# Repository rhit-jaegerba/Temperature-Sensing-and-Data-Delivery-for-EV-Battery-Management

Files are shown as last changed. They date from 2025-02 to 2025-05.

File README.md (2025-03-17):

# Temperature Sensing and Data Delivery for EV Battery Management

This repository contains the codebase for **Temperature Sensing and Data Delivery for EV Battery Management**, a project focused on collecting, processing, and transmitting temperature data to enhance electric vehicle (EV) battery management systems.

## Authors
- Beckett Jaeger  
- Ryan Seidel  
- Alex Herzog  
- Dylan McCain  

## Advisors
- Dr. JianJian Song  
- Dr. Mario Simoni  

## Clients
- Greg Romas  
- Marc Herniter  
- **BWC Team**:  
  - Jack Martin  
  - Jasper Halford  

## Project Details
This project is being developed as part of **Team 09** for the **Senior Design Program** at Rose-Hulman Institute of Technology (2024-2025 academic year).  

It is designed specifically for the **Rose-Hulman Battery Workforce** in support of the **Vigo Voltage Competition Team**, aiming to deliver a reliable, efficient, and scalable system for monitoring and transmitting temperature data critical to the performance and safety of EV battery systems.

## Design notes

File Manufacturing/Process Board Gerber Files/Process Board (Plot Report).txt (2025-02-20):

Plot Report
-----------

Report Written:     Wednesday, February 19, 2025
Project Path:       C:\Users\mccaindm\OneDrive - Rose-Hulman Institute of Technology\Senior Des\Process Board PCB\Process Board\Process Board.prj
Design Path:        C:\Users\mccaindm\OneDrive - Rose-Hulman Institute of Technology\Senior Des\Process Board PCB\Process Board\Process Board.pcb
Design Title:       
Created:            1/19/2025 3:18:48 PM
Last Saved:         2/18/2025 1:24:20 PM
Editing Time:       731 min
Units:              mil (precision 2)

Device Settings
===============

Gerber Settings
===============

    Leading zero suppression.
    G01 assumed throughout.
    Line termination <*> <CR> <LF>.
    3.5 format absolute inches.

    Format commands defined in Gerber file.
    Aperture table defined in Gerber file.
    Hardware arcs allowed.

Drill Settings
==============

    Excellon Format 2
    Format 3.5 absolute in mm.
    Zero suppression Leading

Plots Output
============

    Plot Job: "C:\Users\mccaindm\OneDrive - Rose-Hulman Institute of Technology\Senior Des\Process Board PCB\Process Board\Process Board.mop"

Gerber Output
=============

C:\Users\mccaindm\OneDrive - Rose-Hulman Institute of Technology\Senior Des\Process Board PCB\Process Board\Process Board - Top Silkscreen.gbr

    Layers:
    ------------------
    Top Silkscreen

    D-Code Shape  (thou)
    -----------------------
    D16    Round 11.81
    D20    Round 1.97
    D21    Round 3.94
    D73    Round 5.00
    D74    Round 7.87
    D75    Round 9.84
    D124   Round 3.00

Gerber Output
=============

C:\Users\mccaindm\OneDrive - Rose-Hulman Institute of Technology\Senior Des\Process Board PCB\Process Board\Process Board - Top Copper.gbr

    Layers:
    --------------
    Top Copper

    D-Code Shape  (thou)
    -----------------------------------------------
    D16    Round 11.81
    D18    Round 8.00
    D19    Round 32.00
    D70    Round 66.00
    D71    Round 141.73
    D77    Rectangle 23.62 X 47.24
    D78    Rectangle 23.62 X 47.24  Rotation 90
    D79    Rectangle 11.81 X 31.50  Rotation 90
    D80    Rectangle 11.81 X 31.50
    D81    Square 110.24
    D82    Rectangle 47.24 X 125.98
    D83    Rectangle 66.93 X 208.66
    D84    Rectangle 23.62 X 24.41  Rotation 90
    D85    Rectangle 39.76 X 71.65
    D86    Rectangle 23.62 X 49.21  Rotation 90
    D87    Rectangle 17.72 X 23.62  Rotation 90
    D88    Rectangle 62.99 X 125.98
    D89    Rectangle 23.62 X 24.41
    D90    Rectangle 23.62 X 49.21
    D91    Rectangle 17.72 X 23.62
    D92    Rectangle 37.40 X 110.24
    D93    Rectangle 95.00 X 135.00  Rotation 90
    D94    Rectangle 18.70 X 19.69  Rotation 90
    D95    Rectangle 18.70 X 19.69
    D96    Rectangle 43.31 X 78.74
    D97    Square 31.50
    D125   Rectangle 47.24 X 125.98  Rotation 90
    D126   Rectangle 66.93 X 208.66  Rotation 90

Gerber Output
=============

C:\Users\mccaindm\OneDrive - Rose-Hulman Institute of Technology\Senior Des\Process Board PCB\Process Board\Process Board - Top Solder Mask.gbr

    Layers:
    -------------------
    Top Solder Mask

    D-Code Shape  (thou)
    ------------------------------------------------
    D23    Round 38.00
    D24    Round 72.00
    D25    Round 147.73
    D99    Rectangle 29.62 X 53.24
    D100   Rectangle 29.62 X 53.24  Rotation 90
    D101   Rectangle 17.81 X 37.50  Rotation 90
    D102   Rectangle 17.81 X 37.50
    D103   Square 116.24
    D104   Rectangle 53.24 X 131.98
    D105   Rectangle 72.93 X 214.66
    D106   Rectangle 29.62 X 30.41  Rotation 90
    D107   Rectangle 45.76 X 77.65
    D108   Rectangle 29.62 X 55.21  Rotation 90
    D109   Rectangle 23.72 X 29.62  Rotation 90
    D110   Rectangle 68.99 X 131.98
    D111   Rectangle 29.62 X 30.41
    D112   Rectangle 29.62 X 55.21
    D113   Rectangle 23.72 X 29.62
    D114   Rectangle 43.40 X 116.24
    D115   Rectangle 101.00 X 141.00  Rotation 90
    D116   Rectangle 24.70 X 25.69  Rotation 90
    D117   Rectangle 24.70 X 25.69
    D118   Rectangle 49.31 X 84.74
    D119   Square 37.50
    D127   Rectangle 53.24 X 131.98  Rotation 90
    D128   Rectangle 72.93 X 214.66  Rotation 90

Gerber Output
=============

C:\Users\mccaindm\OneDrive - Rose-Hulman Institute of Technology\Senior Des\Process Board PCB\Process Board\Process Board - Top Paste Mask.gbr

    Layers:
    ------------------
    Top Paste Mask

    D-Code Shape  (thou)
    -----------------------------------------------
    D120   Rectangle 37.31 X 72.74
    D121   Square 25.50
    D129   Rectangle 41.24 X 119.98  Rotation 90
    D130   Rectangle 60.93 X 202.66  Rotation 90
    D150   Rectangle 17.62 X 41.24
    D151   Rectangle 17.62 X 41.24  Rotation 90
    D152   Rectangle 5.81 X 25.50  Rotation 90
    D153   Rectangle 5.81 X 25.50
    D154   Square 104.24
    D155   Rectangle 41.24 X 119.98
    D156   Rectangle 60.93 X 202.66
    D157   Rectangle 17.62 X 18.41  Rotation 90
    D158   Rectangle 33.76 X 65.65
    D159   Rectangle 17.62 X 43.21  Rotation 90
    D160   Rectangle 11.72 X 17.62  Rotation 90
    D161   Rectangle 56.99 X 119.98
    D162   Rectangle 17.62 X 18.41
    D163   Rectangle 17.62 X 43.21
    D164   Rectangle 11.72 X 17.62
    D165   Rectangle 31.40 X 104.24
    D166   Rectangle 89.00 X 129.00  Rotation 90
    D167   Rectangle 12.70 X 13.69  Rotation 90
    D168   Rectangle 12.70 X 13.69

Gerber Output
=============

C:\Users\mccaindm\OneDrive - Rose-Hulman Institute of Technology\Senior Des\Process Board PCB\Process Board\Process Board - GND Plane (Power Plane).gbr

    Layers:
    -----------------------------------------------------------------------------------
    GND Plane  - Plane Isolation Gap 10.00 Thermal Connect Width 10.00 with 4 Spokes

    D-Code Shape  (thou)
    -----------------------------------------
    D12    Round 46.00
    D13    Round 80.00
    D14    Round 66.00  Thermal Relief Pad
    D15    Round 155.73
    D131   Round 32.00  Thermal Relief Pad

Gerber Output
=============

C:\Users\mccaindm\OneDrive - Rose-Hulman Institute of Technology\Senior Des\Process Board PCB\Process Board\Process Board - V3.3 Plane (Power Plane).gbr

    Layers:
    ------------------------------------------------------------------------------------
    V3.3 Plane  - Plane Isolation Gap 10.00 Thermal Connect Width 10.00 with 4 Spokes

    D-Code Shape  (thou)
    -----------------------------------------
    D12    Round 46.00
    D13    Round 80.00
    D15    Round 155.73
    D131   Round 32.00  Thermal Relief Pad

Gerber Output
=============

C:\Users\mccaindm\OneDrive - Rose-Hulman Institute of Technology\Senior Des\Process Board PCB\Process Board\Process Board - Bottom Copper.gbr

    Layers:
    -----------------
    Bottom Copper

    D-Code Shape  (thou)
    -----------------------
    D10    Round 11.81
    D11    Round 32.00
    D12    Round 8.00
    D13    Round 66.00
    D14    Round 141.73

Gerber Output
=============

C:\Users\mccaindm\OneDrive - Rose-Hulman Institute of Technology\Senior Des\Process Board PCB\Process Board\Process Board - Bottom Documentation.gbr

    Layers:
    ------------------------
    Bottom Documentation

    D-Code Shape  (thou)
    -----------------------
    D15    Round 1.97
    D16    Round 3.94

Gerber Output
=============

C:\Users\mccaindm\OneDrive - Rose-Hulman Institute of Technology\Senior Des\Process Board PCB\Process Board\Process Board - Bottom Solder Mask.gbr

    Layers:
    ----------------------
    Bottom Solder Mask

    D-Code Shape  (thou)
    -----------------------
    D17    Round 38.00
    D18    Round 72.00
    D19    Round 147.73

Gerber Output
=============

C:\Users\mccaindm\OneDrive - Rose-Hulman Institute of Technology\Senior Des\Process Board PCB\Process Board\Process Board - Bottom Paste Mask.gbr

    Layers:
    ---------------------
    Bottom Paste Mask

    D-Code Shape  (thou)
    -----------------------

Gerber Output
=============

C:\Users\mccaindm\OneDrive - Rose-Hulman Institute of Technology\Senior Des\Process Board PCB\Process Board\Process Board - Gerber Drill Data - [Through Hole].gbr

    Layers:
    ------------------
    [Through Hole]

    D-Code Shape  (thou)
    -----------------------
    D70    Round 16.00
    D71    Round 40.00
    D20    Round 129.92

NC Drill Output
===============

C:\Users\mccaindm\OneDrive - Rose-Hulman Institute of Technology\Senior Des\Process Board PCB\Process Board\Process Board - NC Drill Data - [Through Hole].drl

    Output:
    ---------------------------
    Plated Round Drill Holes
    Plated Slots

    Tool  Size           Count   ID
    --------------------------------------
    T001  0.01600 inches 118   Z
    T002  0.04000 inches 33    J
    T003  0.12992 inches 9     AA
    --------------------------------------
    Total                160
    --------------------------------------

C:\Users\mccaindm\OneDrive - Rose-Hulman Institute of Technology\Senior Des\Process Board PCB\Process Board\Process Board - NC Drill Data - [Through Hole] (Unplated).drl

    Output:
    -----------------------------
    Unplated Round Drill Holes
    Unplated Slots

    Tool  Size Count   ID
    ----------------------------
    ----------------------------
    Total      0
    ----------------------------

Gerber Output
=============

C:\Users\mccaindm\OneDrive - Rose-Hulman Institute of Technology\Senior Des\Process Board PCB\Process Board\Process Board - Drill Ident Drawing - [Through Hole].gbr

    Layers:
    ------------------
    [Through Hole]

Drill Ident Drawing
===================

    Drill Plated Size Shape ID
    -----------------------------------
    40    Y      100  Round J
    16    Y      100  Round Z
    130   Y      100  Round AA

    D-Code Shape  (thou)
    -----------------------
    D21    Round 100.00
    D22    Round 5.00

Gerber Output
=============

C:\Users\mccaindm\OneDrive - Rose-Hulman Institute of Technology\Senior Des\Process Board PCB\Process Board\Process Board - Board Outline.gbr

    Layers:
    ------------------
    Board Outlines

    D-Code Shape  (thou)
    -----------------------
    D22    Round 5.00

End Of Report.

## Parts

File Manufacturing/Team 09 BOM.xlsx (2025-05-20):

Section | Component | MFG. PROD. # | Unit Price | Quantity | Order Price | Datasheet
Sensor module | TMP112 | TMP112AQDRLRQ1 | $2.07 | 32 | $66.24 | Included in folder (https://www.ti.com/lit/ds/symlink/tmp112-q1.pdf?HQS=dis-dk-null-digikeymode-dsf-pf-null-wwe&ts=1734237533357)
 | Temp Sensor module PCB |  | $32.80 | 1 | $32.80
 | 1k | ERJ-2RKF1001X | $0.10 | 16 | $1.60 | Included in folder (https://www.vishay.com/docs/20008/dcrcw.pdf)
 | 0.01 uF | GCM155R71H103KA55D | $0.10 | 16 | $1.60 | Included in folder (https://industrial.panasonic.com/cdbs/www-data/pdf/RDA0000/AOA0000C304.pdf)
 | RTV | 3140 90 ML MIL-A-46146 | $54.55 | 1 | $54.55 | Included in folder (https://www.dow.com/en-us/document-viewer.html)
 | Thermal Interface Pad | TG-ALC-40-40-0.2-0 | $1.03 | 1 | $1.03 | Included in folder (https://www.tglobaltechnology.com/wp-content/uploads/2023/08/TG-ALC_UK.pdf)
Process Board | ATMEGA328PBXplore Pro | ATMEGA328PB-XMINI | $15.47 | 1 | $15.47 | Included in folder (https://ww1.microchip.com/downloads/en/DeviceDoc/40001906C.pdf)
 | 8-Channel I2C Mux | TCA9548ARGERQ1 | $2.08 | 1 | $2.08 | Included in folder (https://www.ti.com/general/docs/suppproductinfo.tsp?distId=10)
 | Process Board PCB+ stencil |  | $58.39 | 1 | $58.39
 | Regulator – 5V | LMR50410Y5FQDBVRQ1 | $1.47 | 1 | $1.47 | Included in folder (https://www.ti.com/lit/ds/symlink/lmr50410-q1.pdf)
 | Regulator – 3.3V | LMR50410Y3FQDBVRQ1 | $1.47 | 1 | $1.47 | Included in folder (https://www.ti.com/lit/ds/symlink/lmr50410-q1.pdf)
 | 2.2uF | GCM31CR71H225KA55L | $0.15 | 2 | $0.29 | Included in folder (https://search.murata.co.jp/Ceramy/image/img/A01X/G101/ENG/GCJ188R71H104KA12-02B.pdf)
 | 0.1uF | GCM155R71H104KE02J | $0.10 | 2 | $0.20 | Included in folder (https://search.murata.co.jp/Ceramy/image/img/A01X/G101/ENG/GCM155R71H104KE02-01.pdf)
 | 4.7uH - (Derated) | ETQ-P3M6R8KVN | $0.93 | 1 | $0.93 | Included in folder (https://industrial.panasonic.com/cdbs/www-data/pdf/AGL0000/AGL0000C63.pdf)
 | 3.3uH - (Derated) | DFE322520FD-4R7M=P2 | $0.88 | 2 | $1.76 | Included in folder (https://search.murata.co.jp/Ceramy/image/img/A01X/G101/ENG/GCM155R71H104KE02-01.pdfhttps:/search.murata.co.jp/Ceramy/image/img/P02/J(E)TE243A-9104.pdf)
 | 10uF | GRT21BC71E106KE13L | $0.37 | 2 | $0.74 | Included in folder (https://search.murata.co.jp/Ceramy/image/img/A01X/G101/ENG/GRT21BC71E106KE13-01.pdf)
 | 100uF | EEH-ZK1V101XP | $1.24 | 2 | $2.48 | Included in folder (https://industrial.panasonic.com/cdbs/www-data/pdf/RDD0000/ABA0000C1229.pdf)
 | 4.7k | ERJ-2RKF4701X | $0.10 | 20 | $2.00 | Included in folder (https://industrial.panasonic.com/cdbs/www-data/pdf/RDA0000/AOA0000C304.pdf)
 | Diode( for reverse bias protection) | V1P22-M3/H | $0.26 | 1 | $0.26 | Included in folder (https://www.vishay.com/docs/86535/v1p22.pdf)
Connections | Molex Connectors pcb | 5023520401 | $0.82 | 8 | $6.56 | Included in folder (https://tools.molex.com/pdm_docs/pk/PK-502352-002-JP.pdf)
 | Connectors pig tail | 2183231043 | $2.28 | 8 | $18.24 | Included in folder (https://tools.molex.com/pdm_docs/pk/PK-502352-002-JP.pdf)
 | Wires | A2015B-100-ND | $45.76 | 1 | $45.76 | Included in folder (https://www.alphawire.com/disteAPI/SpecPDF/DownloadProductSpecPdf?productPartNumber=3050)
 |  |  |  | Total: | $251.92

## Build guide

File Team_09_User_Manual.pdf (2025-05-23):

1

# Temperature Sensing and Data Delivery for EV Battery Management

## Team 9

## Dylan McCain, Ryan Seidel, Beckett Jaeger, Alex Herzog

2

## Contents

3

# 1. Overview

## 1.1 Purpose of the System

The Temperature Sensing and Data Delivery system is designed to monitor and report battery cell temperatures in the EV battery pack developed by the Rose-Hulman Battery Workforce Challenge Team. Real-time temperature monitoring is essential to prevent thermal runaway and to optimize the cooling and overall performance of the battery pack.

## 1.2 Integration with the EV Battery Pack

The system seamlessly integrates with the EV battery pack by connecting directly to the battery management system (BMS) via an I2C bus. Temperature sensors are strategically placed within the battery modules, ensuring accurate thermal monitoring. The data collected is processed and transmitted for real-time analysis and decision-making.

## 1.3 Components Overview

- Process Board – The central unit responsible for data collection, processing, and communication.
- Sensor Modules – Individual temperature sensors that connect directly to the process board.
- Microcontroller (ATMega328PB) – Runs the system software, manages sensor data, and controls communication.

## 1.4 Basic Operational Principles

The system continuously collects temperature data from up to 32 sensors connected to the process board. The microcontroller processes the data and transmits it over an I2C bus to the BMS. This allows the BMS to monitor battery temperatures in real time and take necessary actions to prevent overheating or thermal imbalances.

# 2. Hardware

## 2.1 Process Board

This section outlines the materials, connections, PCB fabrication, and assembly processes involved in the design and production of the Process Board. It also explains the design choices behind the board. The Process Board includes an ATMEGA328PB microcontroller, eight sensor connectors, two switching regulators, and a multiplexer for sensor addressing.
2.1.1 Fabrication and Assembly
Refer to the appendix for PCB fabrication and assembly instructions.

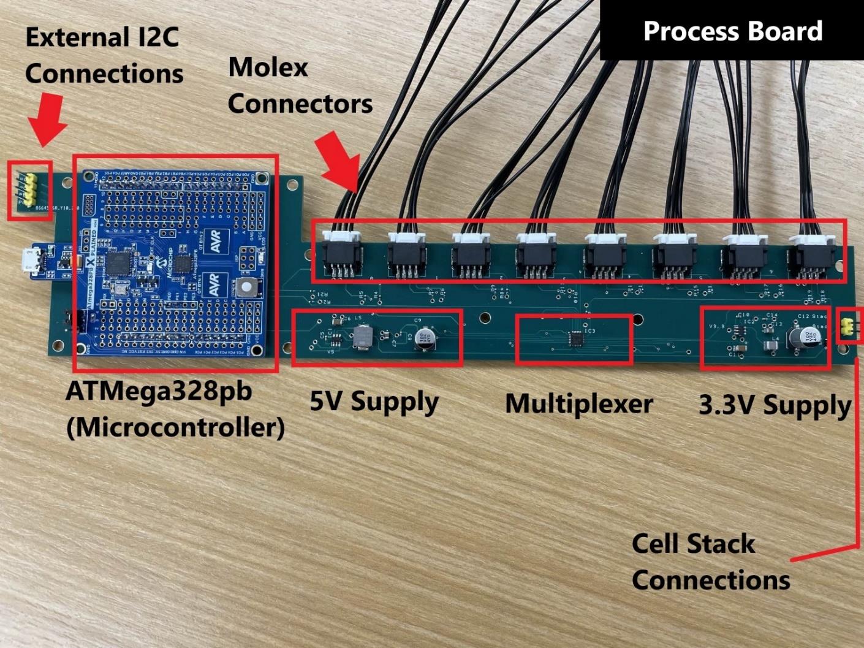
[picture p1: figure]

4

2.1.2 Connections, I/O and testing pads

Figure: Subsection view of the process board 2.1.3 Design and Functionality
PCB Composition

The PCB is a 4-layer board with a signal – ground – 3.3V power – signal stack-up. The ground and power planes help reduce noise and improve signal integrity. The board has a standard thickness of 1.6 mm, with 0.5 oz inner copper and 1 oz outer copper to balance conductivity and thermal performance. A 4-layer design was chosen to provide cleaner signal routing and reliable power distribution.

ATMega328PB Evaluation Board

The ATMega328PB serves as the system’s main processor. It runs the system software, manages communication with the sensors, and processes incoming data before passing it to the BMS. This microcontroller was chosen for its low power consumption, adequate processing capability, and built-in dual I2C capabilities, which simplifies communication with the temperature sensors and the BMS.

5

Sensor Connectors

The system includes eight 4-pin Molex connectors, which serve as the interface for the external temperature sensors. Each connector provides 3.3V power, ground, SDA, and SCL, supporting I2C communication. Each connector can accommodate two sensor boards, totaling four sensors per connector, allowing for efficient expansion while minimizing the number of required connections. The connectors were chosen to provide a low profile and secure interface.

Power Regulation
The power system includes 5V and 3.3V switching regulators, chosen to meet the voltage requirements of different circuit components. Both regulators take in the cell stack voltage and step it down to the necessary levels. The 5V supply powers the ATMega328PB and serves as the pull-up voltage for I2C communication with the BMS. The 3.3V supply is connected to the PCB power plane and powers the rest of the system. A switching regulator was chosen because it met the power requirements, offered a well-documented datasheet for easier integration, and provided greater efficiency compared to a linear regulator.
Sensor Multiplexer (MUX)

The multiplexer (MUX) allows the microcontroller to communicate with multiple sensors using a shared I2C bus. Since the I2C protocol has a limited number of available addresses, the single MUX enables the system to manage 32 sensors without address conflicts. This ensures that the microcontroller can selectively communicate with each sensor as needed, optimizing data collection.

Additional Components
- Resistors: Used as pull-up resistors on the I2C lines to maintain signal integrity and ensure reliable communication.
- Capacitors and Inductors: Used for filtering on the 5V and 3.3V power supplies, reducing noise and stabilizing voltage output.
- Diode: Provides reverse bias protection, preventing damage from incorrect power connections.

## 2.2 Sensor Module

This section outlines the materials, fabrication, and assembly processes involved in the design and production of the sensor module. It also explains the design choices behind the module. The sensor module incorporates two TMP112 temperature sensors along with two passive circuit components.
2.2.1 Fabrication and Assembly
Refer to the appendix for PCB fabrication and assembly instructions.

6

2.2.2 Connections, I/O and testing pads

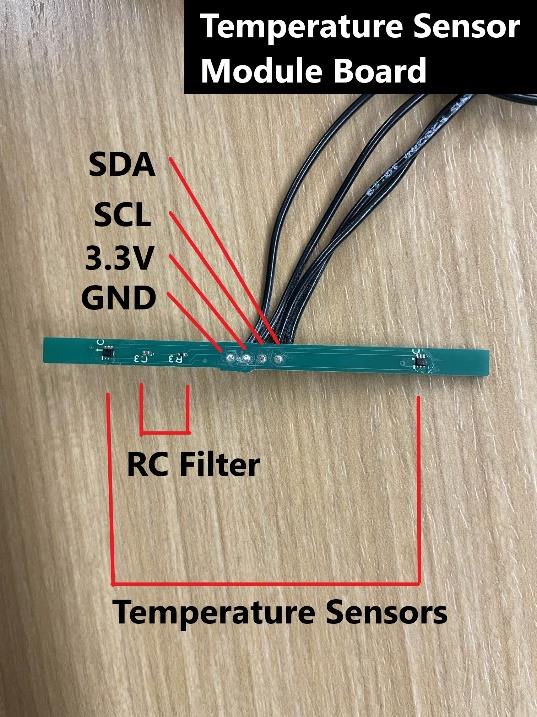
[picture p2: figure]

Figure: Subsection view of the Temp Sensor Board 2.2.3 Design and Functionality
The purpose of the temperature sensors is to measure the temperature of the cell. The temperature sensors are positioned at opposite ends of the sensor module to measure the temperature at both the top and bottom of a cell. The module's height matches that of the cell it is designed to monitor. The sensors are not placed at the extreme top or bottom of the module, as those areas are likely occupied by external structural materials that secure the sensor module in place.
The filter subsection is designed to minimize electrical noise affecting the temperature sensors. Its components were selected to be as small as possible to ensure they do not interfere with the contact between the temperature sensors and the thermal interface pad, which sits between the sensor module and the cell.
The I/O subsection is designed to accommodate small wires reaching the sensor module, as there is insufficient space for a standard connector and the module’s current draw is minimal. Given that the sensor module may be positioned in the middle of the battery pack, where space is extremely limited, through-hole connections were chosen as a practical solution.

7

# 3. Software

## 3.1 GitHub

3.1.1 Repository Overview
Repository: https://github.com/rhit-jaegerba/Temperature-Sensing-and-Data-Delivery-for-EV-Battery-Management (https://github.com/rhit-jaegerba/Temperature-Sensing-and-Data-Delivery-for-EV-Battery-Management)
The GitHub repository for this project contains all of the code for the full usage of this system, the code necessary to replicate the tests that have been run on the system, and simple example files to validate functionality of individual components in the system.
3.1.2 Repository
- NormalOperation
- Arduino file to be flashed onto the process board
- Explained under 3.4 Software Normal Operation
- TestingDataAndFiles
- All files pertaining to the testing we put our system through
- DataLogger.py - software to log temperature data on raspberry pi
- Team_9_Smooth 1.wpf - Thermal chamber profile
- data2-2-2025.csv - Sensor data collected by the DataLogger.py
- Team_9_Smooth_02012025_165947.csv - Oracle Data from thermal chamber
- DemoPlot.py
- Python script to plot Min, Max, Avg works with NormalOperation
- DepreciatedCode
- Old code that may be a helpful reference.

## 3.2 ATMega328pb Bootloader

3.2.1 Required Tools and Downloads
Microchip Studio (v7.0.2594: https://www.microchip.com/en-us/tools- (https://www.microchip.com/en-us/tools-resources/develop/microchip-studio)resources/develop/microchip-studio
Arduino IDE (v2.3.4): https://www.arduino.cc/en/software
Atmega328PB Mini Core Bootloader: https://github.com/stefanrueger/urboot.hex/blob/main/mcus/atmega328pb/watchdog_2_s/external_oscillator_x/16m000000_hz/%2B%2B19k2_baud/uart0_rxd0_txd1/led%2Bb5/urboot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\ (https://github.com/stefanrueger/urboot.hex/blob/main/mcus/atmega328pb/watchdog_2_s/external_oscillator_x/16m000000_hz/%2B%2B19k2_baud/uart0_rxd0_txd1/led%2Bb5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)
ATMega328pb Board: https://www.microchip.com/en-us/development-tool/atmega328p-xmini

8

3.2.2 Installation Instructions

### 1. Flashing the Bootloader

- Reference Sources:
- Preparing Atmega Xplained Mini for Arduino IDE (Windows) (https://github.com/AtmelUniversityFrance/atmel-avr-xmini-boardmanagermodule/wiki/01.-Preparing-atmega*-Xplained-mini-for-Arduino-IDE-use-(MS-Windows))
- Bootloader Installation via Arduino (https://github.com/MCUdude/MiniCore#boards-manager-installation)
- Open Microchip Studio, connect the ATmega328PB via micro USB and make sure the jumper is in the programming position, and open the programming menu.
- Select mEDBG as the tool and ATmega328PB as the device, then click Apply.

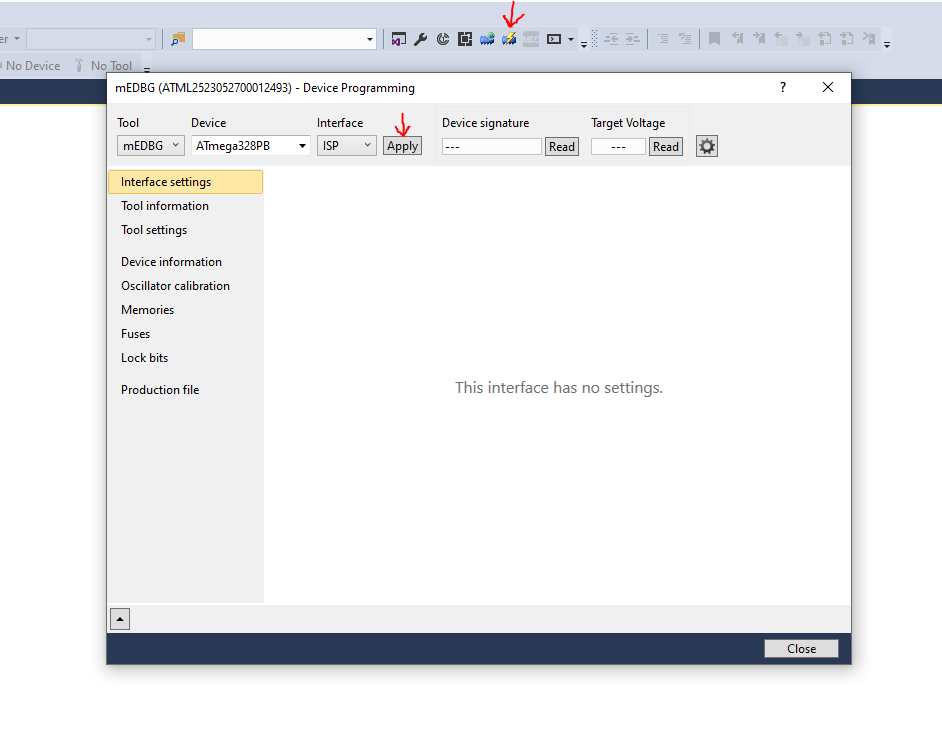
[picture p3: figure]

Figure: Device Programing Window

9

### 2. Configuring ATmega328PB Fuses

Enable the following fuses:

- Brownout detection: 4.3V
- Bootloader size: 256 words (512 bytes)
- Clock source: External (mEDBG from AVR Xplained Mini)

Fuse Values for ATmega328PB:

Fuses\Product | atmega328PB
Low | 0xE0
High | 0xDE
Extended | 0xFC

Click Program to apply the fuse settings.

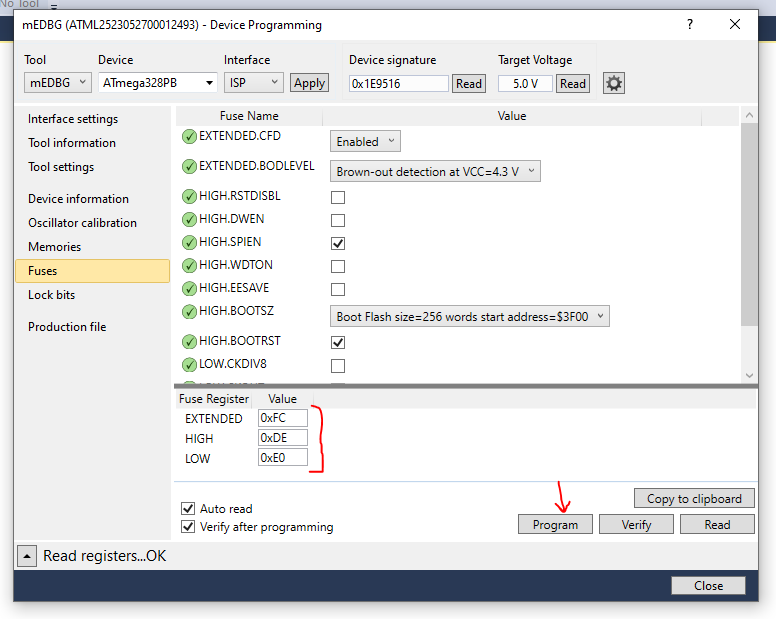
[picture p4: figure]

Figure: Device Programming Fuses window

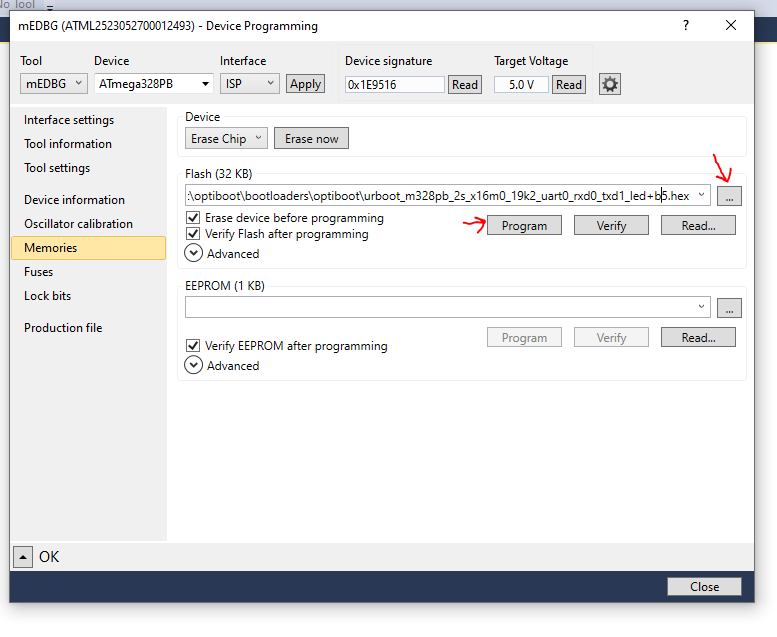
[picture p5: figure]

10

### 3. Flashing the Bootloader

- Open the Memories menu in Microchip Studio.
- Select the downloaded MiniCore Bootloader HEX file:
- urboot_m328pb_2s_x16m0_19k2_uart0_rxd0_txd1_led+b5.hex
- Click Program to flash the bootloader.
- Once completed, you can close Microchip Studio.

Figure: Device Programming Memories window

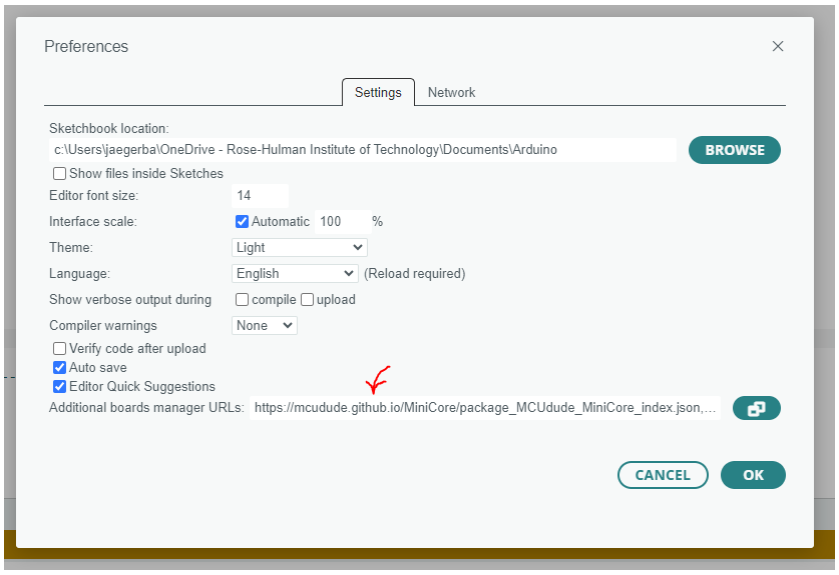
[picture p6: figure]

11

### 4. Setting Up the Arduino IDE

- Open the Arduino IDE, then go to File > Preferences.
- Under Additional Board Manager URLs, paste the following link:
- https://mcudude.github.io/MiniCore/package_MCUdude_MiniCore_index.json
- Click OK.

Figure: Arduino IDE Preferences

12

### 5. Installing MiniCore

- Open the Board Manager from the left menu.
- Search for "MiniCore", then click Install.

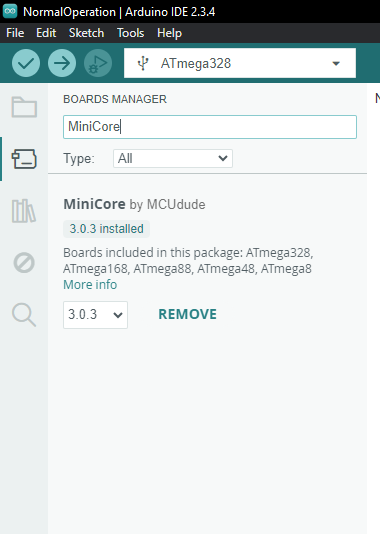
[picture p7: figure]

Figure: Arduino Boards Manager

13

### 6. Configuring Board Settings

Go to Tools > Board and set the following options:

- Board: MiniCore > "ATmega328PB"
- Baud Rate: Default
- BOD: 4.3V
- Bootloader: Yes (UART0)
- Clock: External 16 MHz
- EEPROM: Retained
- Compiler LTO: Disabled
- Variant: 328PB
- Programmer: Xplained Mini

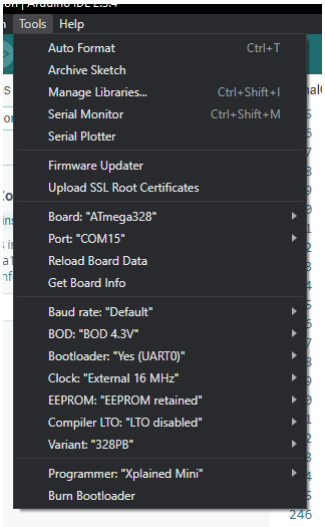
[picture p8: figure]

Figure: Arduino Tools Dropdown

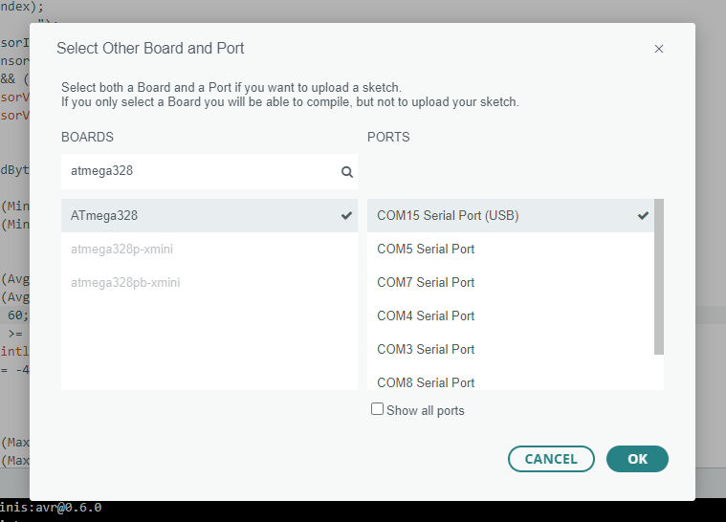
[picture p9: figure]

14

### 7. Selecting Board and Port

- Click the Board and Port menu (USB symbol on the top bar).
- Select ATmega328PB as the board.
- Choose the correct Port that connects to the development board.

Figure: Arduino Board and Port menu

15

### 8. Uploading Code

- Open the desired code using File > Open.
- Upload it to the board using Sketch > Upload Using Programmer.

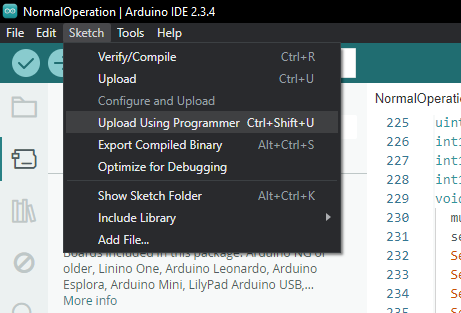
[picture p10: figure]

Figure: Sketch Dropdown menu

### 9. Final Steps

- The board should now be successfully programmed.
- You may see a warning message—this is expected and can be ignored.

Figure: Arduino successful programming console message

16

## 3.3 Software Parameters

Parameters that can easily be modified to alter the operation of the code
connectedSensors: 8x4 array to account for the maximum of 32 sensors. For each sensor, enter a 0 if it is not active, otherwise enter the module that the sensor is associated with. Each process board can support up to 7 modules. Each instance of the system is only aware of the modules it is connected to so there will be multiple instances of modules 1, 2, 3, and 4 throughout the entire battery pack.

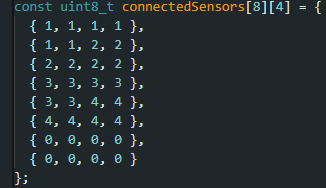
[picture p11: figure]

Figure: Example configuration for connectedSensors WINDOW_SIZE: Configure the size of the sliding window used for digital filtering. The default value is 8. Refer to section 3.4 for more information.
WINDOW_TOLERANCE: Configure the tolerance of the sliding window calculation. The default is 25%. Refer to section 3.4 for more information.
SLAVE_ADDRESS: Set the Process boards I2C address.

## 3.4 Software Normal Operation

Upon startup the Atmega will automatically initialize both of its I2C buses. Next, all of the connected sensors will be initialized. Any errors that occur will be printed on the serial monitor. The main loop will start collecting temperature data from the connected sensors. The code will iterate through each connected sensor and collect values from that sensor as determined by the value of WINDOW_SIZE. The average value will then be calculated, and each value will be compared against this average. Any values that are outside of the tolerance set by WINDOW_TOLERANCE will then be discarded and the average will then be recalculated with the new values. This new average will be stored for that sensor until it is recalculated. These values will be continuously updated while the system is running.

17

If the value for a specific sensor is requested, the last calculated average for that sensor will be sent. When the max, min, or average for a specific module is requested, that value will be found from the last sensor averages calculated and sent.

# 4. System Integration

## 4.1 Connecting the Process Board to Sensor Modules

Each sensor module connects to the process board through one of the Molex connectors to optimize space. Each Molex connector supports two temperature sensor modules.

### 4.1.1 Steps to Connect the Sensor Modules:

### 1. Prepare the Molex Pigtail:

a. Take a male Molex pigtail, and solder two new leads onto each of the four existing wires, resulting in a total of eight leads.
b. Use heat shrink tubing over all solder joints.

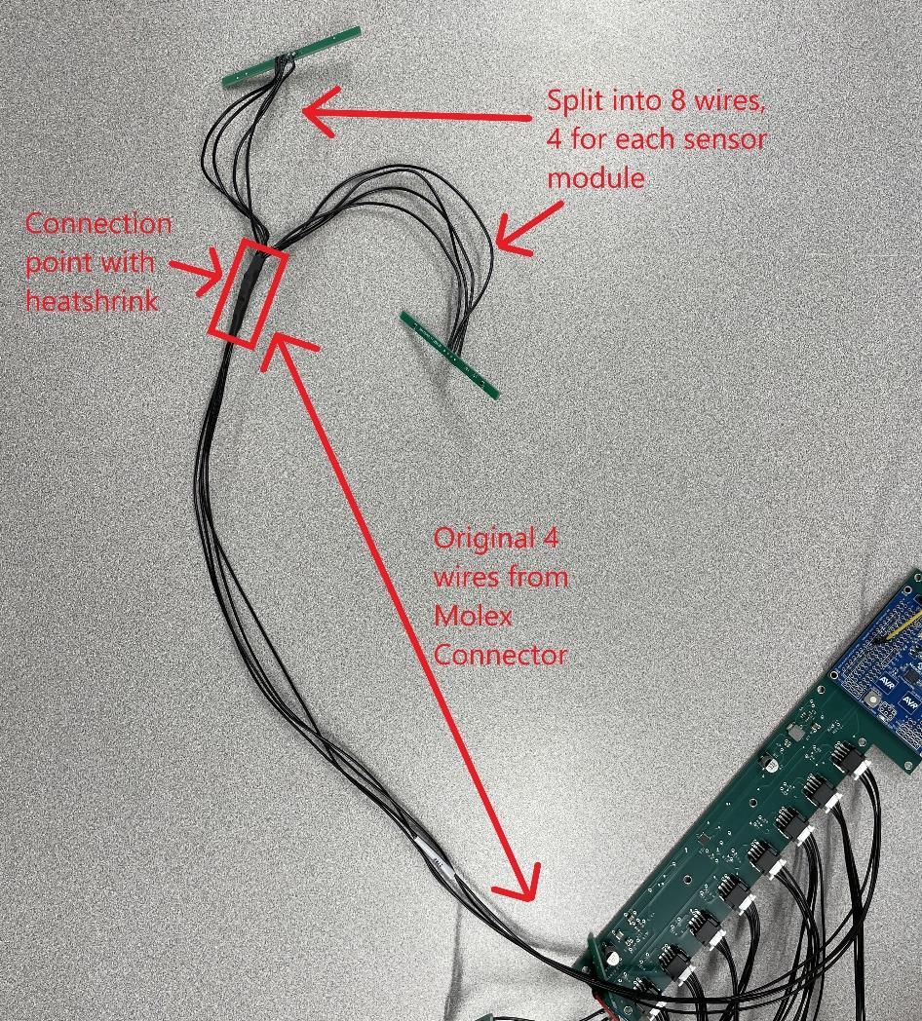
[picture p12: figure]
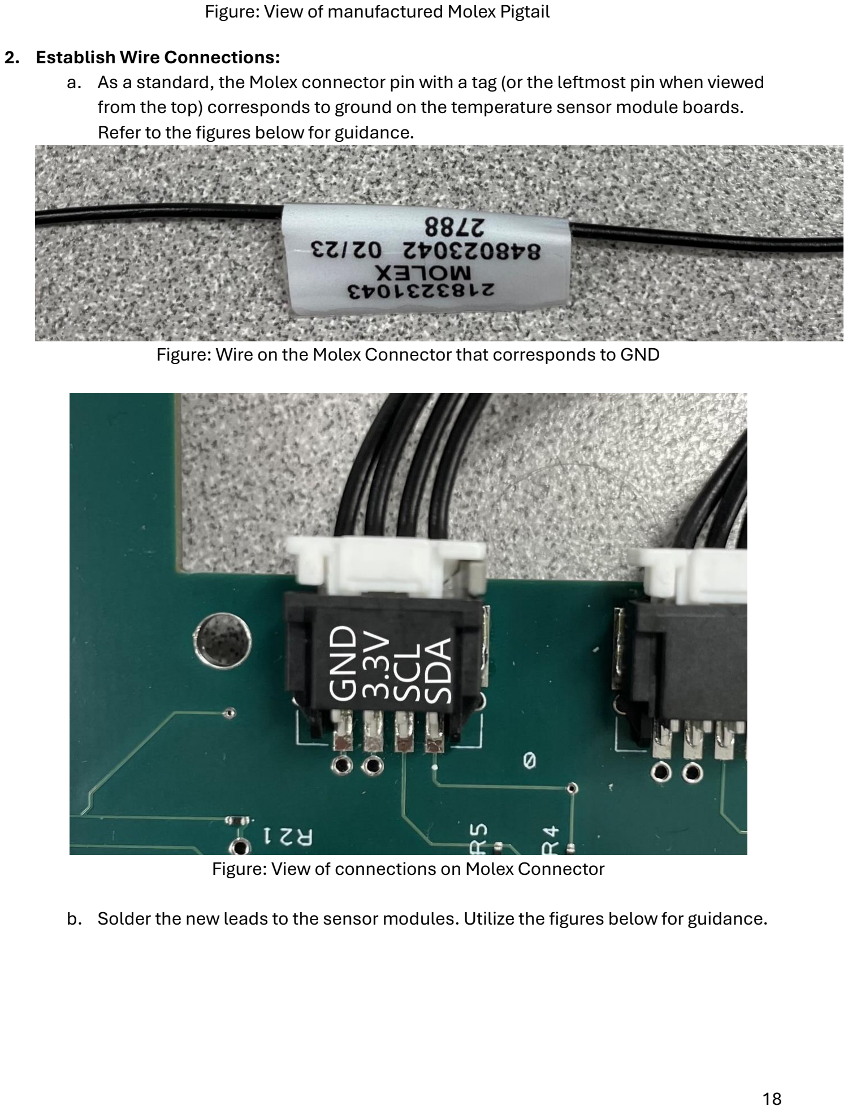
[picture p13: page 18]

18

Figure: View of manufactured Molex Pigtail

### 2. Establish Wire Connections:

a. As a standard, the Molex connector pin with a tag (or the leftmost pin when viewed from the top) corresponds to ground on the temperature sensor module boards. Refer to the figures below for guidance.

Figure: Wire on the Molex Connector that corresponds to GND

Figure: View of connections on Molex Connector

b. Solder the new leads to the sensor modules. Utilize the figures below for guidance.

19

Figure: Subsection view of the Temp Sensor Board

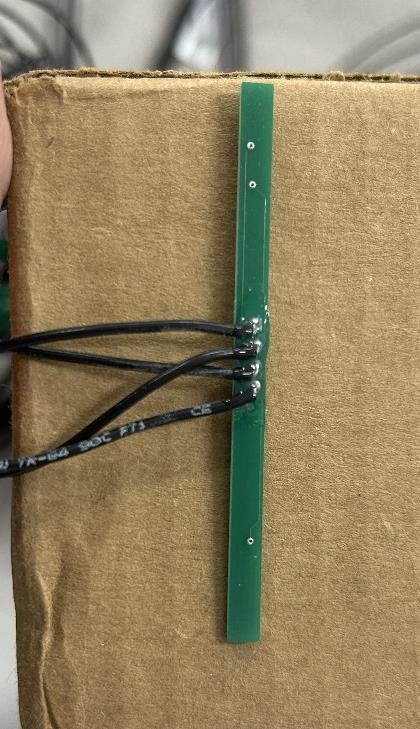
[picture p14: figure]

Figure: View from behind of a soldered temperature sensor module

## 4.2 attaching sensor Module to Cell

The sensor modules are attached to the battery cell using a Thermal Interface Pad (TIP). This pad functions like double-sided tape but has enhanced thermal conductivity, allowing for more efficient temperature sensing.

20

### 4.2.1 Application Process:

### 1. Preparing the Thermal Interface Pad:

a. Cut the TIP to approximately 3 mm x 3 mm for each of the TMP112 temperature sensors to ensure proper coverage.
b. Ensure the pad is cut cleanly for optimal adhesion and thermal transfer.

### 2. Applying the Thermal Interface Pad:

a. Place the cut TIP on the top of the case over both TMP112 temperature sensors on the module.
b. Ensure the pad is securely adhered to the sensor surface.

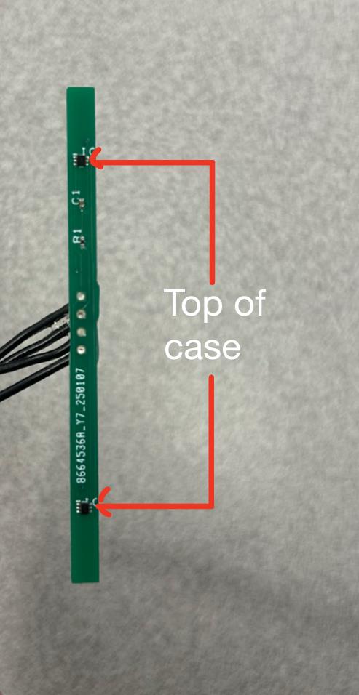
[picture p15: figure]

Figure: Image of the front face of the temperature sensor module

### 3. Mounting the Sensor Module to the Cell:

a. Press the sensor module (with the TIP applied) firmly against the cell.
b. Secure it in place using zip ties to maintain consistent contact while the adhesive sets.
c. Allow 24 hours for the adhesive to fully cure before removing the zip ties.

21

## 4.3 Configuring the I2C Communication

4.3.1 Overview of I2C Communication
The Temperature Sensing and Data Delivery system communicates with the Battery Management System (BMS) via an I2C bus, enabling real-time temperature monitoring of the EV battery pack. The microcontroller (ATMega328PB) functions as the I2C slave, responding to requests from the BMS, which acts as the I2C master.
The system supports up to 32 temperature sensors, with data aggregated by the process board before being transmitted over I2C. Temperature readings are made available through a structured register map, allowing the BMS to efficiently poll and retrieve data.
4.3.1 Hardware Connections

Figure: Process board I2C pinout

The Temperature Sensing and Data Delivery system operates with 3.3V logic levels and interfaces with the Battery Management System (BMS) over an I2C bus.
Required Connections:
- SDA (Data Line): Connect to BMS SDA
- SCL (Clock Line): Connect to BMS SCL
- Shared ground or cell negative between process board and BMS.

22

External I2C Pull-up Resistors:
We highly recommend installing 4.7kΩ pull-up resistors on the SDA and SCL lines.
Additional Debug Connections:
Mux SDA Debug & Mux SCL Debug are available but are not required for standard operation. These pins provide access to the secondary I2C channel used for communication with the sensor multiplexer and are intended for debugging purposes only.
4.3.1 Addressing and Device Selection
The Temperature Sensing and Data Delivery system operates as an I2C slave device with a default address of 0x20. If the address needs to be changed, refer to Section 3.3 - Software Parameters. To read temperature data, the master must first send a command byte specifying the desired sensor or system metric.
Single Sensor Command Byte Structure:
Bits [7:4] – Multiplexer (MUX) index (0–7)
Bits [3:0] – Sensor index within the selected MUX (0–3)
Example:
If requesting data from MUX port 3 and sensor 2, the command byte is: 0x32 (MUX = 3, Sensor = 2) Entire Cell Stack Module Command Values:
Bits [7:4] – Cell Stack Module value (9–F) {Module index + 0x9}
Bits [3:0] – Data To request (0-2) {0: Minimum, 1: Average, 2: Maximum}
Example:
If requesting data from Cell Stack Module 2 and you want the Maximum, the command byte is: 0xA2 (Module index = 2, Maximum = 2)
If the command byte specifies an invalid MUX or sensor index or an invalid Cell Stack Module Command, the device will not return valid data.
4.3.1 Reading Data from the Sensor
To read temperature data, the BMS master must:
1. Send a command byte to specify the desired sensor or system metric.
2. Read two bytes from the slave device.
3. Combine the bytes into a 16-bit signed integer.
4. Scale the value by multiplying by 0.0625 to convert to degrees Celsius.
A python example is available here: https://github.com/rhit-jaegerba/Temperature-Sensing-and-Data-Delivery-for-EV-Battery-Management/blob/main/DemoPlot.py (https://github.com/rhit-jaegerba/Temperature-Sensing-and-Data-Delivery-for-EV-Battery-Management/blob/main/DemoPlot.py)

23

# 5. Operation Guide

## 5.1 Powering the System

Refer to the technical specifications section in the appendix for the exact voltage range the process board can accept. Labels near the edge of the process board indicate the correct voltage source connections (“Cell Stack +” and “Cell Stack -”).
5.1.1 Special Notes for Battery Workforce Challenge
We recommend that the Battery Workforce Challenge Team use a single Cell Stack Module (5 Cells in series gives a voltage range of 15-20.75V) to power the process board. If the Battery Workforce Challenge Team chooses to use an ADBMS6830 alongside a process board to monitor multiple Cell Stack Modules, careful consideration must be given to the overall power connections. The Process Board and the ADBMS6830 must both utilize the same ground for safe operation. Ground refers to the point that has the lowest voltage among the Cell Stack Modules connected in this case. For 3 Cell Stack Modules (15 Cells in series), ground would be the negative terminal of the 15th Cell. Refer to the GitHub link below for guidance and examples. https://github.com/rhit-jaegerba/Temperature-Sensing-and-Data-Delivery-for-EV-Battery-Management/tree/main/Power_Grounding_Diagrams (https://github.com/rhit-jaegerba/Temperature-Sensing-and-Data-Delivery-for-EV-Battery-Management/tree/main/Power_Grounding_Diagrams)

## 5.2 Programming the System

The Atmega328PB includes a jumper that allows programming via the micro-USB port (With no jumper the Atmega328PB is in the program position by default). Refer to the figures below for guidance on the correct jumper position.

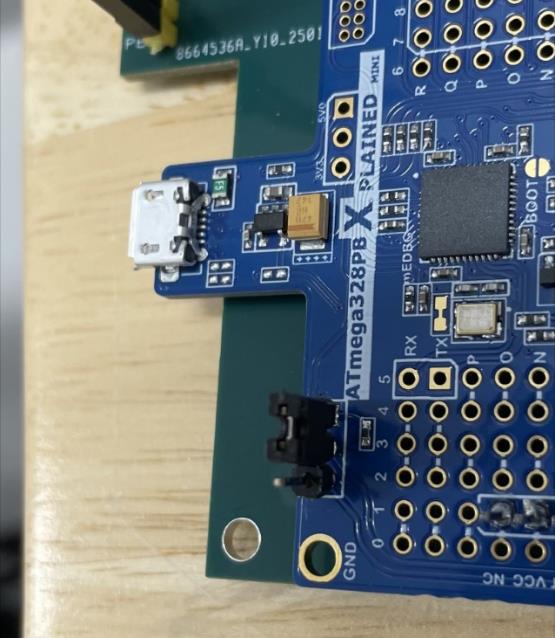
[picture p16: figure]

Figure: Atmega328PB jumper in program position

24

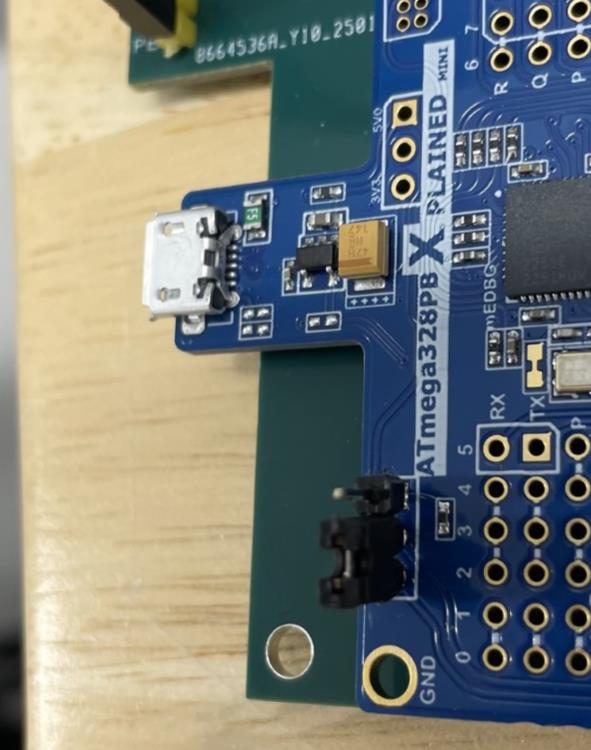
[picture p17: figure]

Figure: Atmega328PB jumper in power position

Make sure the jumper is set to the program position, then follow the steps below in the Arduino IDE to upload the correct code to the Atmega328PB.
- Open the NORMAL_FILE using File > Open.
- Upload it to the board using Sketch > Upload Using Programmer.

25

Figure: Sketch Dropdown menu

- The board should now be successfully programmed.
- You may see a warning message—this is expected and can be ignored.

Figure: Arduino successful programming console message

After successfully programming the Atmega328PB, move the jumper to the power position.

## 5.3 System Setup Successful

The system will function properly if the steps in sections 5.1 and 5.2 are followed. For guidance on system integration, refer to section 4 of this document.

26

# 6. Appendix

## 6.1 Technical Specifications

The table below summarizes the key operating parameters for the Temperature Sensing and Data Delivery system. The "Recommended Operating Features" column lists the conditions under which the system is designed to perform optimally. The "Absolute Maximum" column shows the limits beyond which the system may become unreliable or sustain damage.

Note: These values are based on design targets and sensor specifications. For best performance and longevity, always operate within the recommended range.
Parameter | Recommended Operating Conditions | Absolute Maximum | Notes
Process Board Input Voltage (“Cell Stack Connections”, see Hardware Section for location on board) | 15.0 V to 20.75 V | 4V Minimum 36V Maximum | The system’s power circuitry is designed to operate from the voltage produced by a stack of 5 battery cells in series. The Abs Max/Min values come from the switching regulator Datasheet.
External I2C Communication Characteristics (“I2C Connections”, see Hardware Section for location on board) | Refer to the Atmega328pb Datasheet (Table 33-9): https://ww1.microchip.com/downloads/en/DeviceDoc/40001906 C.pdf (https://ww1.microchip.com/downloads/en/DeviceDoc/40001906C.pdf) VCC=5V | Refer to the Atmega328pb Datasheet (Table 33-9): https://ww1.microchip.com/downloads/en/DeviceDoc/40001906 C.pdf (https://ww1.microchip.com/downloads/en/DeviceDoc/40001906C.pdf) VCC=5V | Utilizing the external I2C ports does not require pull-up resistors.
External I2C Communication Speed | 100kHz | Up to 400 kHz fast-mode | N/A
Temperature Sensor Accuracy (From –40 C to 125 C) | N/A | ±2°C | This is the BWC’s requirement for the system and has been verified to by testing through the range of -40°C to 125°C. Temperature values (Avg) obtained from I2C communication

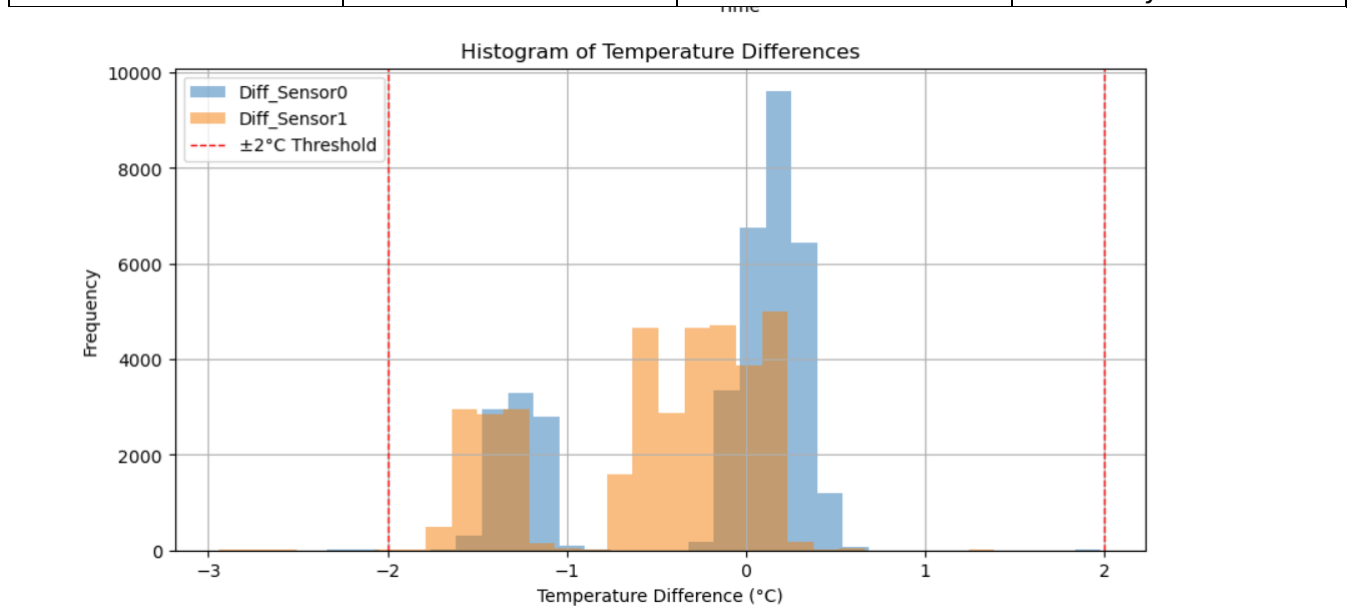
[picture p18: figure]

27

| | | with our device can be expected to be within ±2°C of the actual temperature in the environment being measured.
System Temperature Range | 0°C to 60°C | -40°C to 125°C | This is based off the rating AECQ100/200 rating of all components in the system.
System Temperature Resolution | N/A | 0.0625 °C
Individual Temperature Sensor Polling Rate | Up to 50 Hz | Up to 50 Hz | A 50 Hz rate is optimal for accurate data filtering; higher rates may be used in test modes but could overwhelm the I2C bus or processing routines.
Power Consumption | Active mode: Under 1W | Active mode: Under 3W | Operating within recommended power limits is critical to prevent overheating and preserve battery efficiency.

Figure: Absolute difference in temperature between a temperature sensor and the environment

## 6.2 Reference Diagrams and Schematics

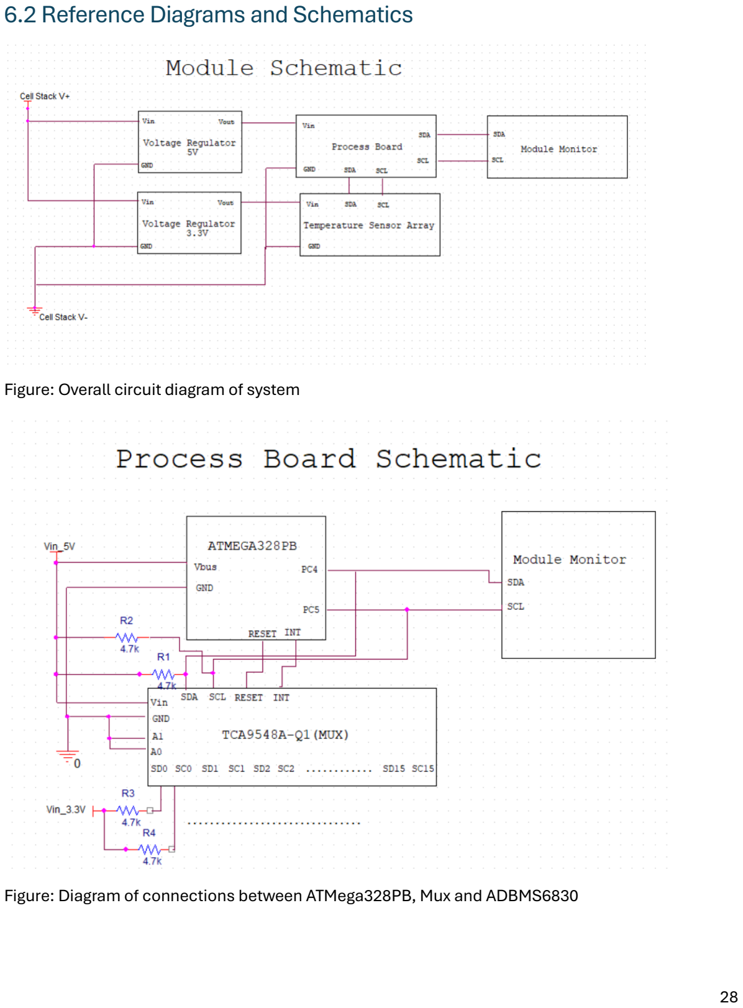
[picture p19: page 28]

28

Figure: Overall circuit diagram of system

Figure: Diagram of connections between ATMega328PB, Mux and ADBMS6830

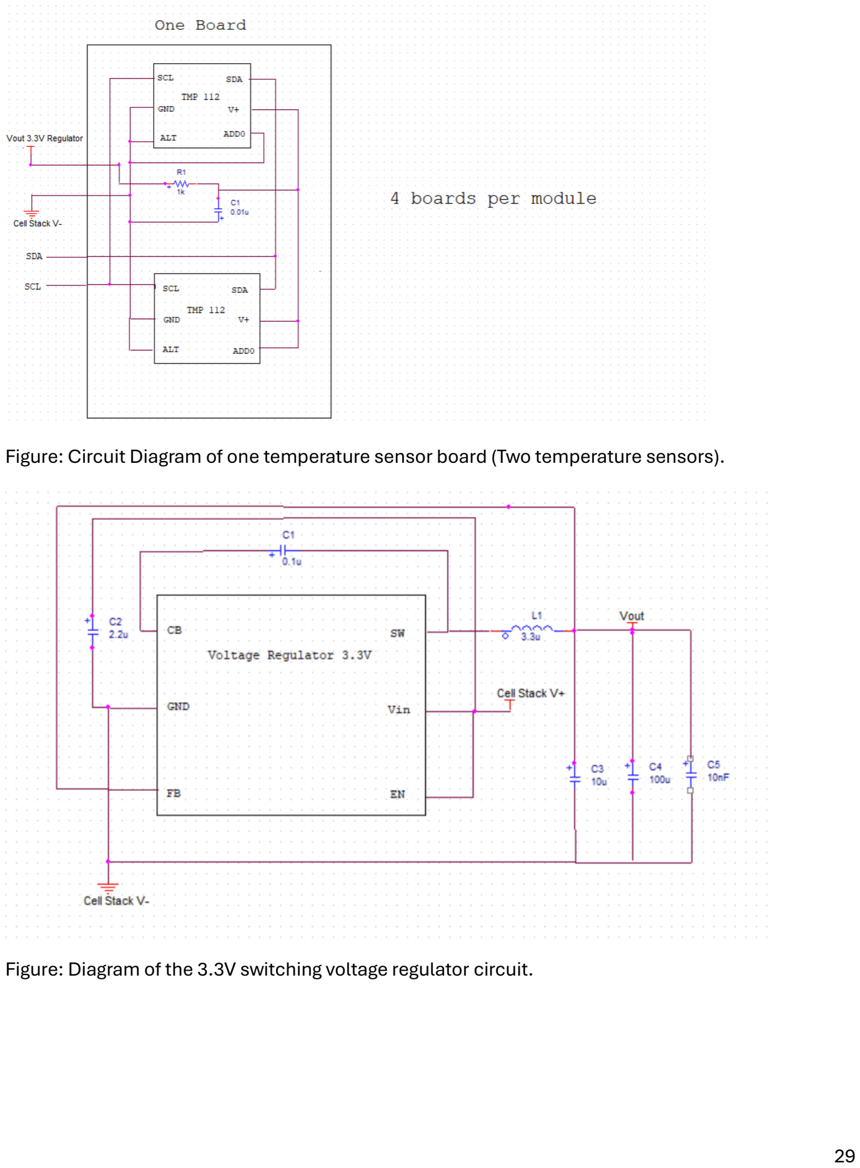
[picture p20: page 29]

29

Figure: Circuit Diagram of one temperature sensor board (Two temperature sensors).

Figure: Diagram of the 3.3V switching voltage regulator circuit.

30

Figure: Diagram of the 5V switching voltage regulator circuit.

## 6.3 Fabrication & Assembly

6.3.1 Bill of Materials
Before beginning fabrication and assembly, ensure all materials listed in the bill of materials are acquired. The bill of materials includes the exact number of components required to make each board (Process Board and Sensor Module). It is advisable to order spare components, as manual fabrication is not always perfect, and parts may be lost. For expensive components, having one or two extras is recommended, while for cheaper components, keeping an additional ten to twenty is a good precaution.
Bill of Materials:
https://github.com/rhit-jaegerba/Temperature-Sensing-and-Data-Delivery-for-EV-Battery-Management/tree/main/Manufacturing (https://github.com/rhit-jaegerba/Temperature-Sensing-and-Data-Delivery-for-EV-Battery-Management/tree/main/Manufacturing)
6.3.2 Fabrication & Assembly Process
For efficient fabrication and assembly of the PCBs used in this product, it is highly recommended to order and use a stencil. A stencil greatly accelerates the manufacturing process. This section of the guide explains the fabrication process with the assumption that a stencil has been obtained for each PCB (Process Board PCB and Sensor Module PCB). Additionally, a microscope is essential for

31

PCB fabrication and assembly, as many components are extremely small and difficult to place accurately.
6.3.2.1 Applying Solder Paste
Place the PCB on a flat surface and align the stencil so that its holes match the pads on the board. Secure the stencil with tape to prevent movement during solder paste application. Once secured, apply solder paste on top of the stencil and spread it evenly to fill all the holes. Verify that solder paste has been applied to every hole, then carefully lift the stencil and proceed with component placement.
6.3.2.2 Placing Components

Place the PCB under a microscope for better visibility during component placement. While components can be placed in any order, it is recommended to start with the smallest ones first to avoid obstruction from larger components. Use the board’s schematics to ensure correct placement, referencing the silkscreen markings (e.g., C05 on the board corresponds to C05 on the schematic). Handle small components carefully, as they can be easily lost. Pay close attention to components with polarity and ensure they are oriented correctly. Additionally, some components must be placed in a specific orientation—silkscreen indicators and datasheets can provide guidance. Continue placing components in their designated locations until all are correctly positioned.

6.3.2.3 Reflow Oven
After placing all components, the PCB is ready for the reflow oven. The oven's temperature settings depend on the type of solder paste used, so refer to the solder paste specifications and the reflow oven manual for the appropriate temperature and duration. Once the reflow process is complete, visually inspect the board to confirm that all components are properly attached and securely soldered to the pads.
6.3.2.4 Atmega328PB
Before mounting the Atmega328PB onto the process board, solder a pin header in the designated area shown in the figure below. This header will serve as a hardware control, allowing the Atmega328PB to operate using either board power or micro-USB power.

32

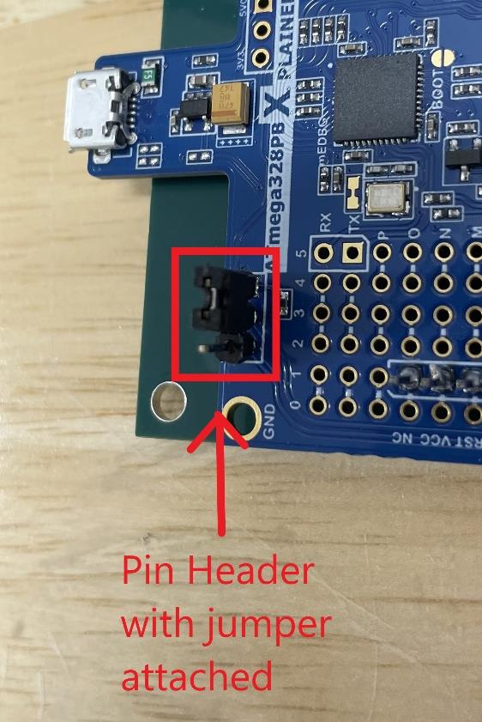
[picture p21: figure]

Figure: View of soldered pin header with jumper attached The Atmega328PB is mounted using pin headers and through-hole connections on the process board, with all connections soldered by hand. Every though-hole pin on the process board PCB should be filled with a pin header. Ensure proper alignment by referring to the pictures below.

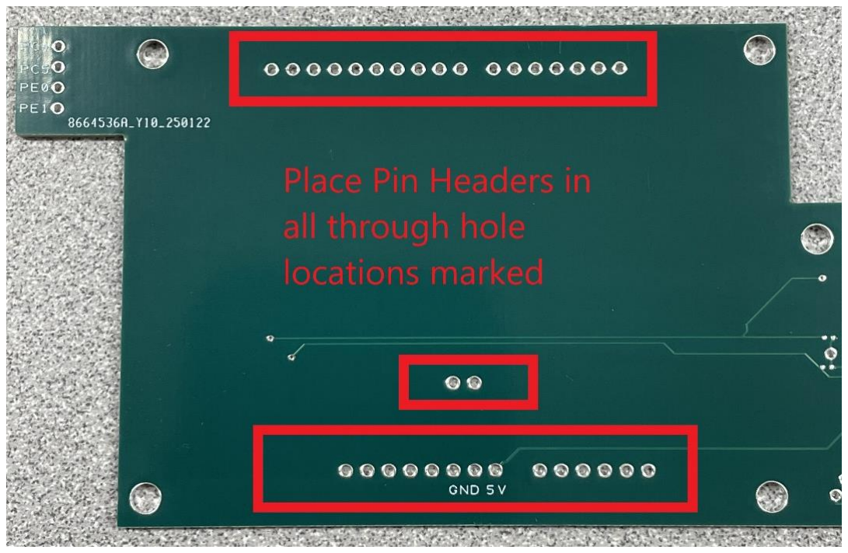
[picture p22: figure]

Figure: Empty process board

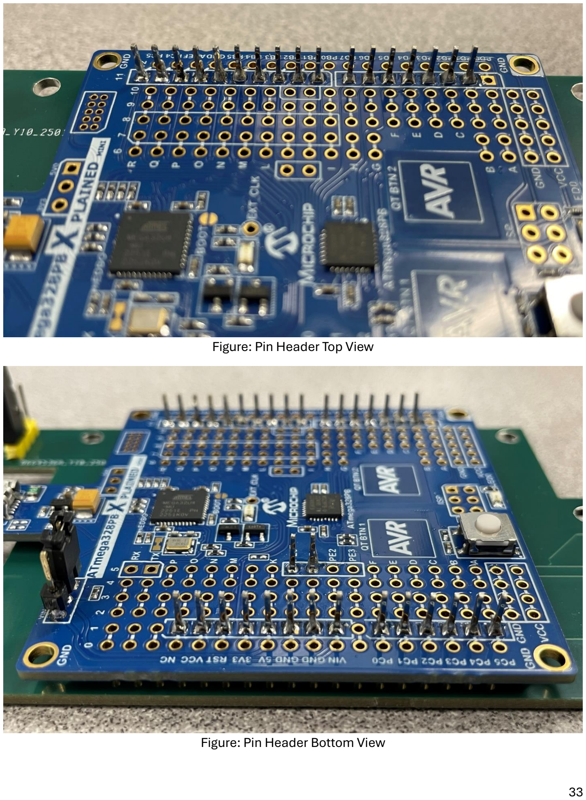
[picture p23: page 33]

33

Figure: Pin Header Top View

Figure: Pin Header Bottom View

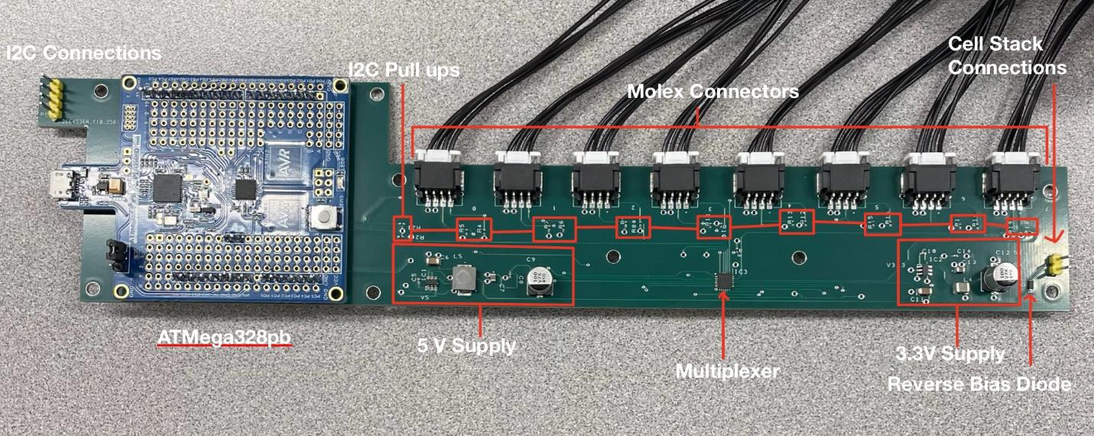
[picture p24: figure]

34

Figure: Subsection view of the process board

## 6.4 Glossary of Terms

- BMS: Battery Management System
- I2C: Inter-Integrated Circuit communication protocol
- SMT: Surface-Mount Technology
- AEC-Q100/Q200: Automotive Electronics Council standards for component reliability
- Cell Stack Module: A module within the battery pack, containing cells, designed by the Battery Workforce Challenge.
- ADBMS6830: A device that monitors the voltages of cells in a Cell Stack Module

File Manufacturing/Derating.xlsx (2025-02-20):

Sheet: Sheet1
Capacitors
Component | Type | Rated Voltage (V) | Operating Temperature Range(C) | Operating Voltage (V) | Rated Voltage at TS(V) | Rated Voltage at TD1(V) | Voltage at TD2(V) | Margin( Percent of Max Max Voltage)
EEH-ZK1V101XP | Fixed, Electrolytic (Dry), Aluminum (Polarized) | 35 | -55 to 125 | 5 | 24.5 | 14 | 7 | 71.43%
GRT21BC71E106KE13L | Fixed, Ceramic, Chip | 25 | -55 to 125 | 5 | 15 | 10 | N/A | 33.33%
GCM155R71H104KE02J | Fixed, Ceramic, Chip | 50 | -55 to 125 | 5 | 30 | 20 | N/A | 16.67%
GCM31CR71H225KA55L | Fixed, Ceramic, Chip | 50 | -55 to 125 | 5 | 30 | 20 | N/A | 16.67%
GCM155R71H103KA55D | Fixed, Ceramic, Chip | 25 | -55 to 125 | 5 | 15 | 10 | N/A | 33.33%
Resistors
Component | Type | Power dissipated(W) | Rated Voltage (V) | Operating Temperature Range(C) | Derated Power dissipated | Derated Voltage | T1 | T2 | Operating Voltage(V) | Operating Power(W) | Margin( Percent of Max Voltage) | Margin( Percent of Power Dissipated)
ERJ-2RKF4701X | Fixed, Film, Chip, ER | 0.063 | 50 | -55 to 155 | 0.0378 | 40 | 70 | 121 | 5 | 0.025 | 12.50% | 66.14%
ERJ-2RKF1001X | Fixed, Film, Chip, ER | 0.063 | 50 | -55 to 155 | 0.0378 | 40 | 70 | 121 | 5 | 0.025 | 12.50% | 66.14%
Component | Type | Rated Saturation Current(A) | Rated Current due to Temperature Rise 40 degree above ambient(A) | Operating Temperature Range(C) | Derated Saturation Current(A) | Derated Current due to Temperature Rise 40 degree above ambient(A) | Operating Current(A) | Margin( Percent of Max Current)
DFE322520FD-4R7M=P2 | CHIP COIL | 3.4 | 2 | -40 to 125 | 3.06 | 1.8 | 0.1 | 5.56%
ETQ-P3M6R8KVN | CHIP COIL | 8.1 | 3.6 | -55 to 155 | 7.29 | 3.24 | 0.1 | 3.09%
 |  |  | #VALUE!
Component | Type | Rated Max Vin(V) | Rated Power Dissipation(W) | Rated Max Tj(C) | Rated Max Iout(A) | Max Operating Vin (V) | Max Power Dissipated Operating(W) | Derated Power Dissipation(W) | Derated Max Tj(C) | Derated Max Iout(A) | Margin( Percent of Power Dissipated)
LMR50410Y5FQDBVRQ1 | monolithic | 36 | 0.722 | 150 | 1 | 20.75 | 0.5202312139 | 0.5415 | 112.5 | 0.8 | 96.07%
LMR50410Y3FQDBVRQ1 | monolithic | 36 | 0.722 | 150 | 1 | 20.75 | 0.5202312139 | 0.5415 | 112.5 | 0.8 | 96.07%
TCA9548ARGERQ1 | monolithic | 5.25 | 2 | 125 | 0.025 | 5 | 1.136363636 | 1.5 | 93.75 | 0.02 | 75.76%
TMP112AQDRLRQ1 | monolithic | 3.6 | 0.6 | 125 | 0.003 | 3.3 | 0.3095238095 | 0.45 | 93.75 | 0.0024 | 68.78%
Diodes
Component | Type | Rated PIV(V) | Rated Surge Currnet(A) | Rated Forward Current(A) | Rated Max Tj(C) | Max Operating PIV | Max Foreward Current(A) | Derated PIV | Derated Surge Currnet(A) | Derated Forward Current(A) | Derated Max Tj(C) | Margin( Percent of Max PIV) | Margin( Percent of Forward Current)
V1P22-M3/H | Schottky | 160 | 25 | 1 | 175 | 21.5 | 0.025 | 112 | 12.5 | 0.5 | 125 | 19.20% | 5.00%

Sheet: Sheet2
 | Fixed, Electrolytic (Dry), Aluminum (Polarized) |  |  | Fixed, Ceramic, Chip
Capacitors
Component | Type | Rated Voltage (V) | Operating Temperature Range(C) | Operating Voltage (V) | Rated Voltage at TS(V) | Rated Voltage at TD1(V) | Voltage at TD2(V) | Margin( Percent of Max Max Voltage)
EEH-ZK1V101XP | Fixed, Electrolytic (Dry), Aluminum (Polarized) | 35 | -55 to 125 | 5 | 24.5 | 14 | 7 | 71.43%
GRT21BC71E106KE13L | Fixed, Ceramic, Chip | 25 | -55 to 125 | 5 | 15 | 10 | N/A | 33.33%
GCM155R71H104KE02J | Fixed, Ceramic, Chip | 50 | -55 to 125 | 5 | 30 | 20 | N/A | 16.67%
GCM31CR71H225KA55L | Fixed, Ceramic, Chip | 50 | -55 to 125 | 5 | 30 | 20 | N/A | 16.67%
GCM155R71H103KA55D | Fixed, Ceramic, Chip | 25 | -55 to 125 | 5 | 15 | 10 | N/A | 33.33%
Resistors
Component | Type | Power dissipated(W) | Rated Voltage (V) | Operating Temperature Range(C) | Derated Power dissipated | Derated Voltage | T1 | T2 | Operating Voltage(V) | Operating Power(W) | Margin( Percent of Max Voltage) | Margin( Percent of Power Dissipated)
ERJ-2RKF4701X | Fixed, Film, Chip, ER | 0.063 | 50 | -55 to 155 | 0.0378 | 40 | 70 | 121 | 5 | 0.025 | 12.50% | 66.14%
ERJ-2RKF1001X | Fixed, Film, Chip, ER | 0.063 | 50 | -55 to 155 | 0.0378 | 40 | 70 | 121 | 5 | 0.025 | 12.50% | 66.14%
Component | Type | Rated Saturation Current(A) | Rated Current due to Temperature Rise 40 degree above ambient(A) | Operating Temperature Range(C) | Derated Saturation Current(A) | Derated Current due to Temperature Rise 40 degree above ambient(A) | Operating Current(A) | Margin( Percent of Max Current)
DFE322520FD-4R7M=P2 | CHIP COIL | 3.4 | 2 | -40 to 125 | 3.06 | 1.8 | 0.1 | 5.56%
ETQ-P3M6R8KVN | CHIP COIL | 8.1 | 3.6 | -55 to 155 | 7.29 | 3.24 | 0.1 | 3.09%
 |  |  | #VALUE!
Component | Type | Rated Max Vin(V) | Rated Power Dissipation(W) | Rated Max Tj(C) | Rated Max Iout(A) | Max Operating Vin (V) | Max Power Dissipated Operating(W) | Derated Power Dissipation(W) | Derated Max Tj(C) | Derated Max Iout(A) | Margin( Percent of Power Dissipated)
LMR50410Y5FQDBVRQ1 | monolithic | 36 | 0.722 | 150 | 1 | 21 | 0.5202312139 | 0.5415 | 112.5 | 0.8 | 96.07%
LMR50410Y3FQDBVRQ1 | monolithic | 36 | 0.722 | 150 | 1 | 21 | 0.5202312139 | 0.5415 | 112.5 | 0.8 | 96.07%
TCA9548ARGERQ1 | monolithic | 5.25 | 2 | 125 | 0.025 | 5 | 1.136363636 | 1.5 | 93.75 | 0.02 | 75.76%
TMP112AQDRLRQ1 | monolithic | 3.6 | 0.6 | 125 | 0.003 | 3.3 | 0.3095238095 | 0.45 | 93.75 | 0.0024 | 68.78%
 |  |  |  |  |  |  |  |  |  |  |  | Margin( Percent of Max PIV) | Margin( Percent of Forward Current)
 |  |  |  |  |  |  |  |  |  |  |  | 19.20% | 5.00%
Diodes
Component | Type | Rated PIV(V) | Rated Surge Currnet(A) | Rated Forward Current(A) | Rated Max Tj(C) | Max Operating PIV | Max Foreward Current(A) | Derated PIV | Derated Surge Currnet(A) | Derated Forward Current(A) | Derated Max Tj(C)
V1P22-M3/H | Schottky | 160 | 25 | 1 | 175 | 21.5 | 0.025 | 112 | 12.5 | 0.5 | 125

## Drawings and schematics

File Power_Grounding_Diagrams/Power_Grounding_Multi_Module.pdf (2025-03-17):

# Inside 1st Battery Module

## Temp Sense System

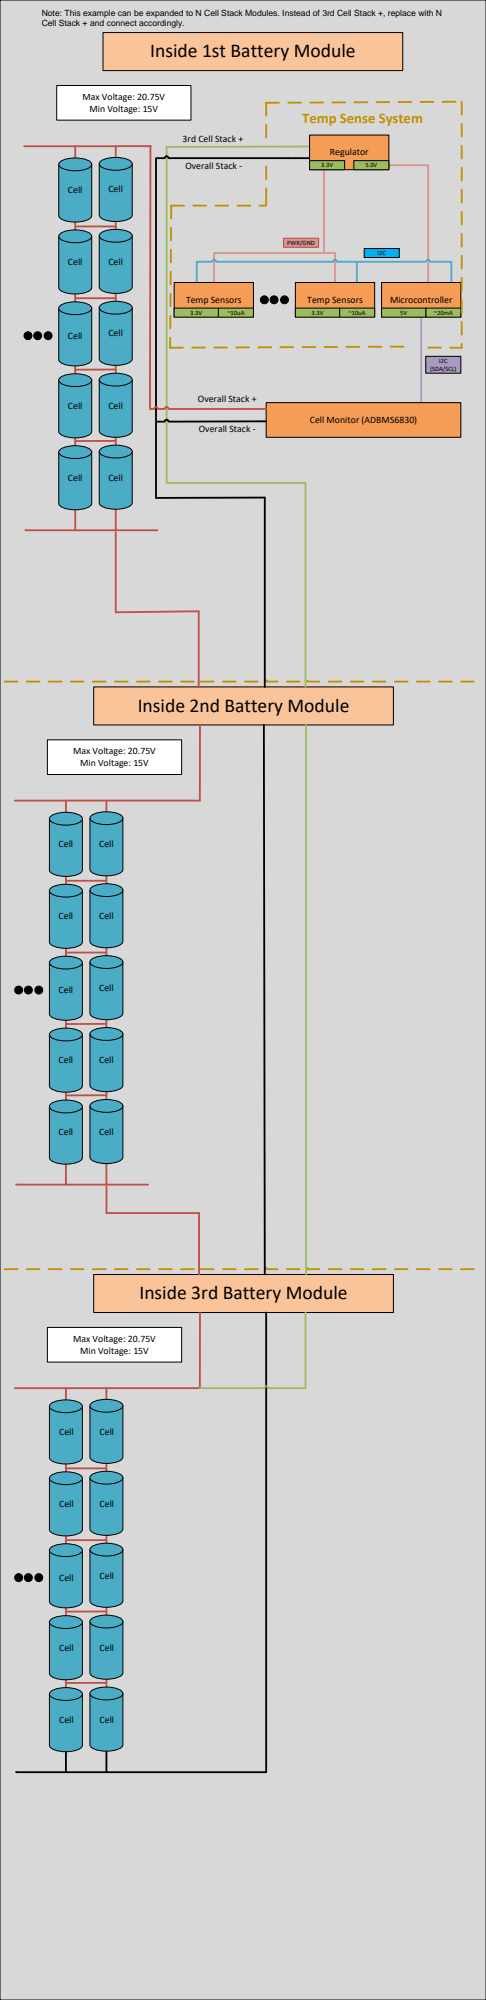
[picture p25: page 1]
Max Voltage: 20.75V Min Voltage: 15V; Temp Sensors; Microcontroller; Cell; Regulator; PWR/GND; Cell Monitor (ADBMS6830); I2C (SDA/SCL); 3rd Cell Stack +; Overall Stack -; Overall Stack +

Inside 2nd Battery Module

Inside 3rd Battery Module

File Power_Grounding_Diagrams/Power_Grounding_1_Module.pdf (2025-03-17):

# Inside Battery Module

## Temp Sense System

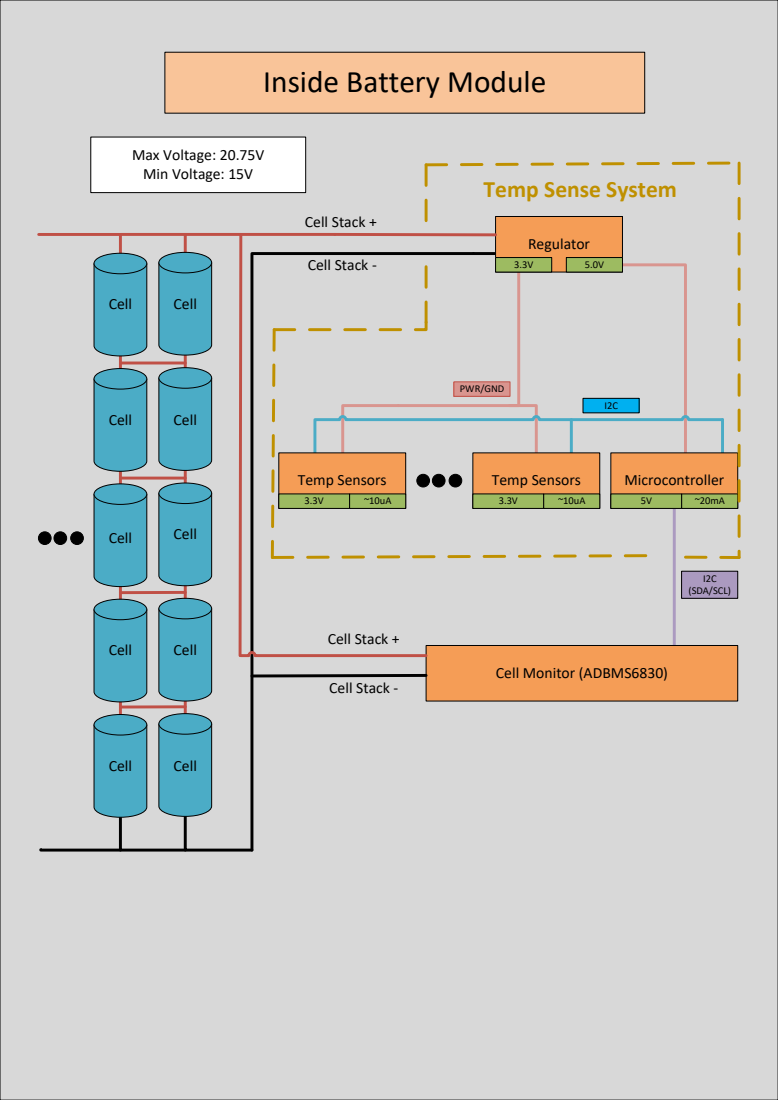
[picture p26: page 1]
Max Voltage: 20.75V Min Voltage: 15V; Temp Sensors; Microcontroller; Cell; Regulator; PWR/GND; Cell Monitor (ADBMS6830); I2C (SDA/SCL); Cell Stack +; Cell Stack -

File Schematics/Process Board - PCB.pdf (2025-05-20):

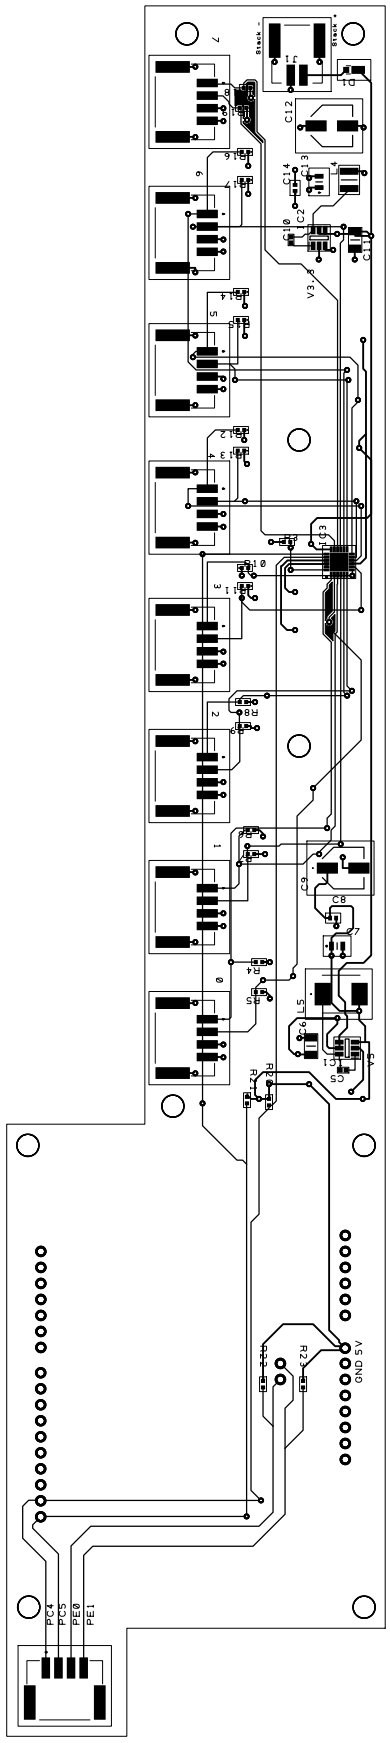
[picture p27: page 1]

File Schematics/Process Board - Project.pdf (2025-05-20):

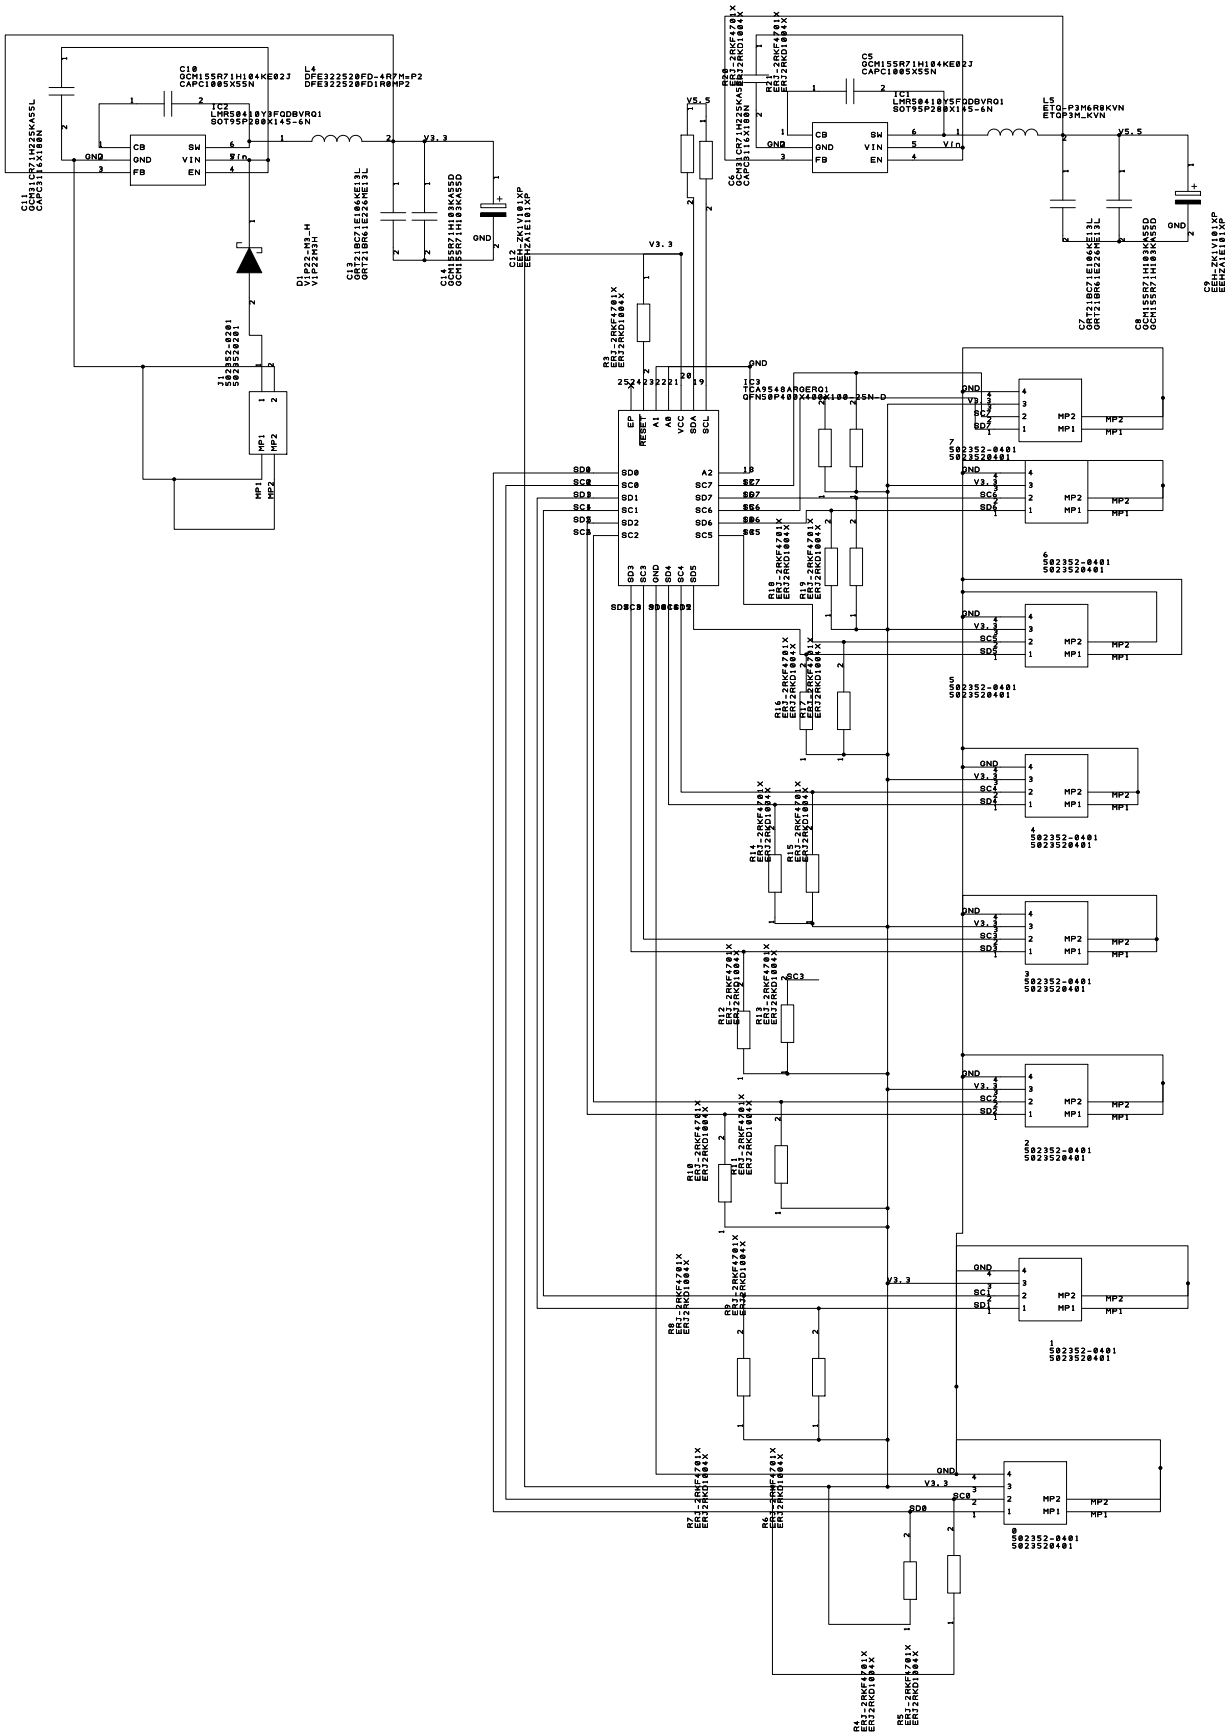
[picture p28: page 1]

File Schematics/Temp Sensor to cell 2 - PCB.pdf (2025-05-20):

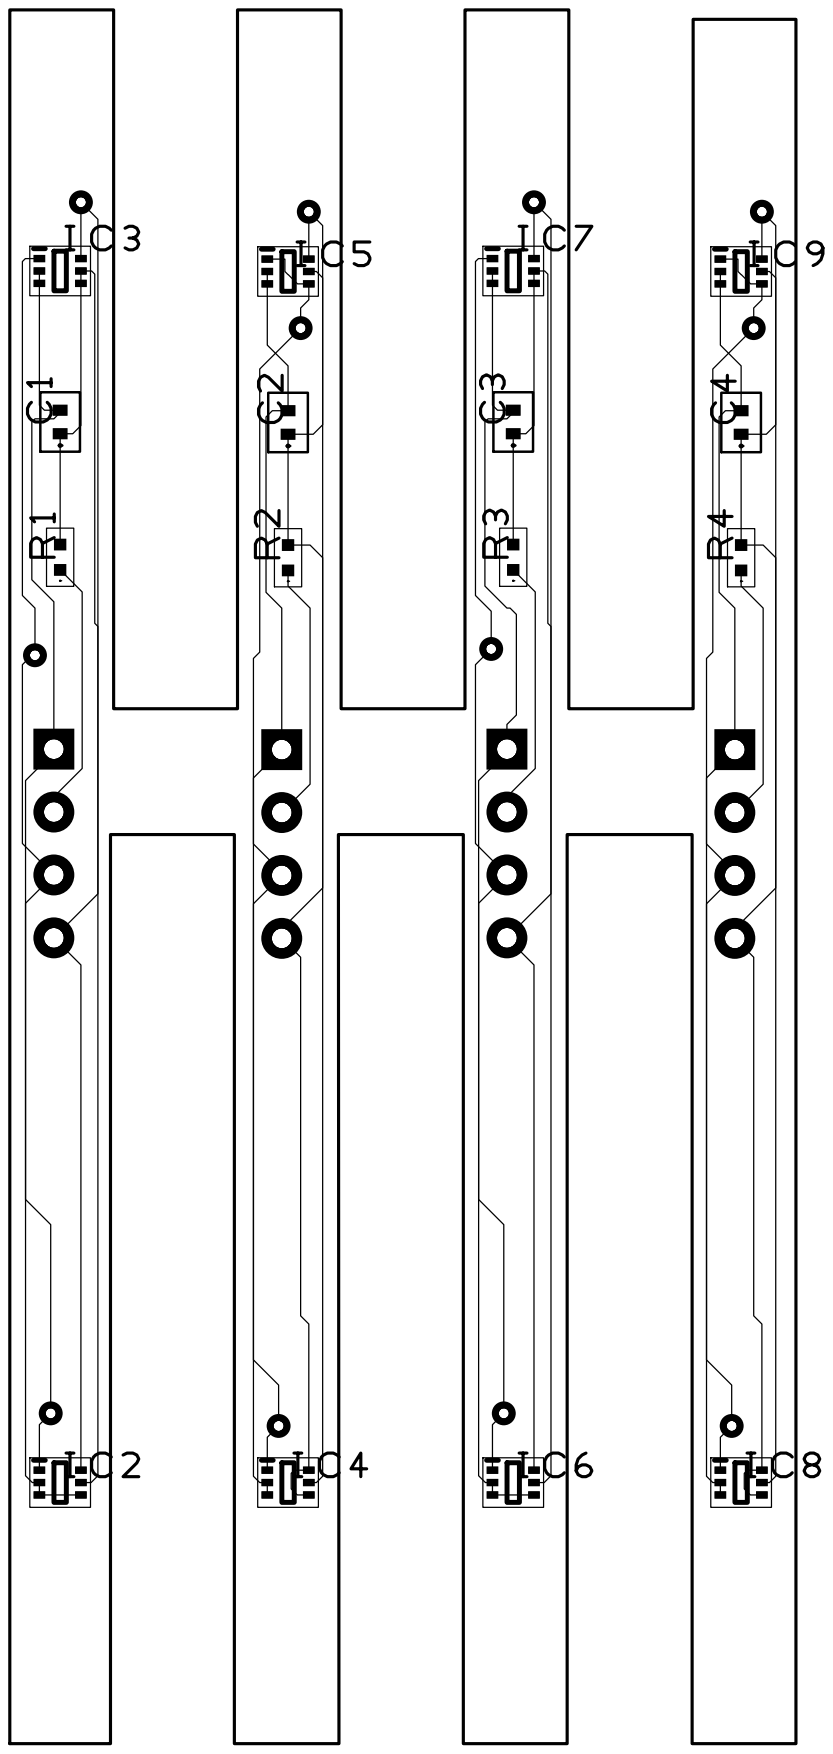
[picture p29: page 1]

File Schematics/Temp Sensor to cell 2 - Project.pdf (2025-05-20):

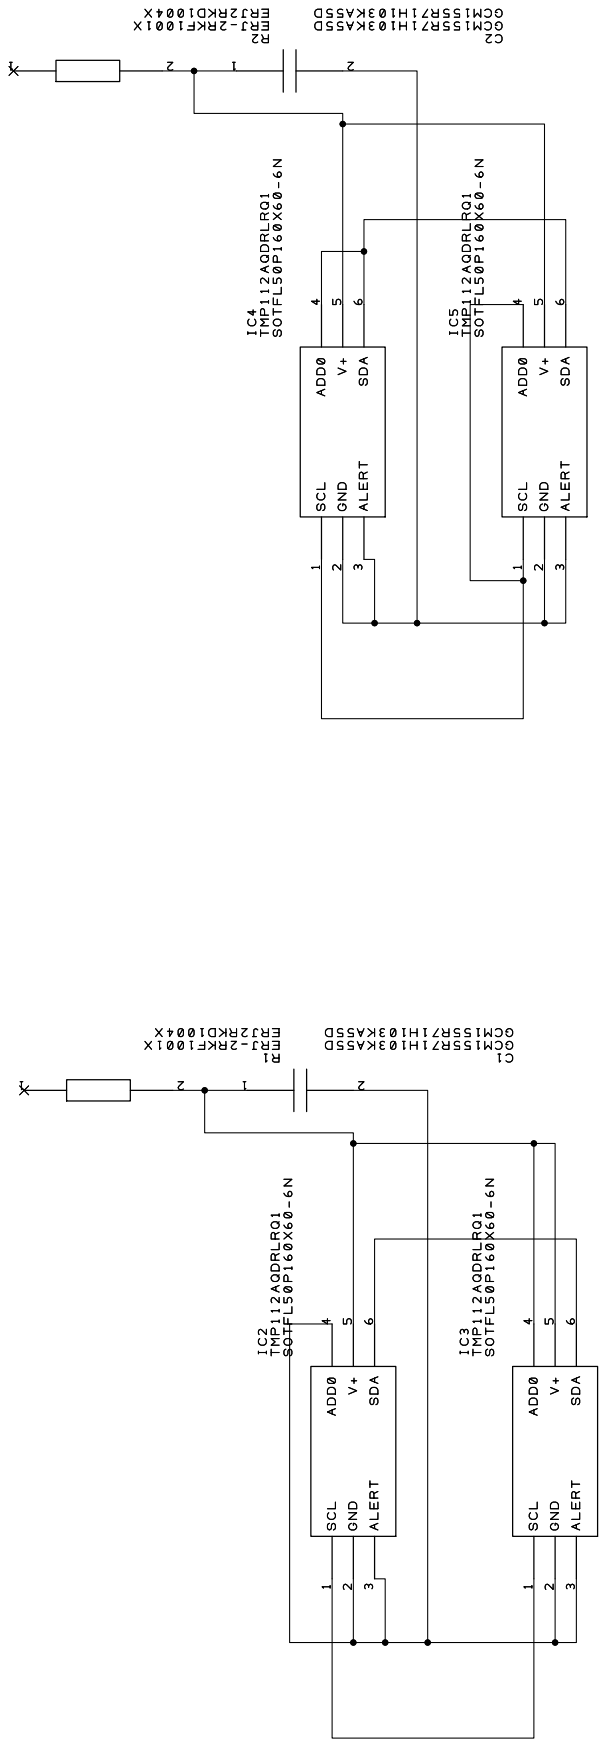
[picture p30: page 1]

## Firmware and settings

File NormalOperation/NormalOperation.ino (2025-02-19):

#include <Wire.h>
#include <Wire1.h>

const uint8_t NUMBER_OF_MODULES = 3;
uint16_t moduleMaxTemperature[NUMBER_OF_MODULES];
uint16_t moduleAvgTemperature[NUMBER_OF_MODULES];
uint16_t moduleMinTemperature[NUMBER_OF_MODULES];
const uint8_t WINDOW_SIZE = 8;        //Size of the Floating Average Window
const float WINDOW_TOLERANCE = 0.25;  //Tolerance of the Floating Average Window

//TCA9548A I2C Mux
#include <SparkFun_I2C_Mux_Arduino_Library.h>  //Click here to get the library: http://librarymanager/All#SparkFun_I2C_Mux
QWIICMUX mux;

const uint8_t MUX_ADDRESS = 0x70;
const uint8_t NUMBER_OF_MUX_PORTS = 8;



//TMP112 temperature sensor
const uint8_t TMP_ADDRESSES[4] = { 0x48, 0x49, 0x4A, 0x4B };
const uint8_t NUMBER_OF_TMP_ADDRESSES = 4;
#define TEMPERATURE_REGISTER 0x00
#define CONFIG_REGISTER 0x01
#define T_LOW_REGISTER 0x02
#define T_HIGH_REGISTER 0x03

#define SLAVE_ADDRESS 0x20

//Sensors connected to the system
//presentSensors(Mux port 0-7, TMP_ADDRESSES 0-3)
//0-Not Connected
//x>0-Module number
const uint8_t connectedSensors[8][4] = {
  { 2, 2, 2, 2 },
  { 1, 1, 0, 0 },
  { 1, 1, 1, 1 },
  { 1, 1, 1, 1 },
  { 1, 1, 1, 1 },
  { 1, 1, 1, 1 },
  { 1, 1, 1, 1 },
  { 1, 1, 1, 1 }
};

int16_t sensorValues[8][4] = { 0 };  //Holds the last calculated average for each sensor

int16_t currentValues[WINDOW_SIZE];
int16_t firstAverage = 0;
int16_t secondAverage = 0;
uint8_t averageCounter = 0;
int16_t currentTemp = 0;

void setup() {
  Serial.begin(9600);
  Wire.begin();

  if (mux.begin(MUX_ADDRESS) == false) {
    Serial.println("Mux not detected. Freezing...");
    while (1)
      ;
  }
  Serial.println("Mux detected");

  for (int i = 0; i < NUMBER_OF_MUX_PORTS; i++) {
    mux.setPort(i);
    for (int j = 0; j < NUMBER_OF_TMP_ADDRESSES; j++) {
      //sensorValues[i][j][0] = 0; //Initalize array;
      if (connectedSensors[i][j] > 0) {
        configureSensor(TMP_ADDRESSES[j]);
        if (!initializeTMP112(TMP_ADDRESSES[j])) {
          Serial.println("Cannot connect to mux port: " + String(i) + " Address: " + String(TMP_ADDRESSES[j]));
          while (1)
            ;
        }
      }
    }
  }

  // Initialize the secondary I2C bus as a Slave
  Wire1.begin(SLAVE_ADDRESS);
  Wire1.onReceive(receiveEvent);  // Callback for data received
  Wire1.onRequest(requestEvent);  // Callback for data requested
  Serial.println("Slave I2C Initialized");
}

void loop() {
  // collect sensor

  for (int i = 0; i < NUMBER_OF_MUX_PORTS; i++) {
    mux.setPort(i);
    for (int j = 0; j < NUMBER_OF_TMP_ADDRESSES; j++) {
      if (connectedSensors[i][j] > 0) {
        for (int z = 0; z < WINDOW_SIZE; z++) {
          currentTemp = readTemp(TMP_ADDRESSES[j]);
          currentValues[z] = currentTemp;
          firstAverage += currentTemp;
        }

        firstAverage /= WINDOW_SIZE;

        for (int y = 0; y < WINDOW_SIZE; y++) {
          if (currentValues[y] < (firstAverage * (1 + WINDOW_TOLERANCE)) && currentValues[y] > (firstAverage * (1 - WINDOW_TOLERANCE))) {
            secondAverage += currentValues[y];
            averageCounter++;
          }
        }

        secondAverage /= averageCounter;
        sensorValues[i][j] = secondAverage;
        firstAverage = 0;
        secondAverage = 0;
        averageCounter = 0;
      }
    }
  }


  //Process Data
/*  for (int i = 0; i < 8; i++) {
    for (int j = 0; j < 4; j++) {
      Serial.print(sensorValues[i][j] * 0.0625);
      Serial.print("\t");  // Tab space for formatting
    }
    Serial.println();  // New line after each row
  } */
  delay(1000);
  Serial.println();
  //calculateModuleMin(2);
  //calculateModuleMax(2);
  //calculateModuleAverage(2);
  Serial.println();
}

bool initializeTMP112(uint8_t address) {
  Wire.beginTransmission(address);
  return Wire.endTransmission() == 0;
}

void configureSensor(uint8_t address) {
  setConversionRate(address, 2);    // Set conversion rate to 4 Hz
  setExtendedMode(address, false);  // Standard mode (-55°C to 128°C)
  setAlertPolarity(address, true);  // Active HIGH alert
  setAlertMode(address, false);     // Comparator mode
  setFaultQueue(address, 0);        // Trigger alert on first fault
  setHighTempF(address, 85.0);      // Set T_HIGH threshold to 85°F
  setLowTempF(address, 84.0);       // Set T_LOW threshold to 84°F
}

int16_t readTemp(uint8_t address) {
  Wire.beginTransmission(address);
  Wire.write(TEMPERATURE_REGISTER);
  Wire.endTransmission();
  Wire.requestFrom(address, (uint8_t)2);  // Request 2 bytes from the sensor

  uint8_t msb = Wire.read();
  uint8_t lsb = Wire.read();

  int16_t temp = (msb << 4) | (lsb >> 4);
  if (temp & 0x800) temp |= 0xF000;  // Handle negative temperatures

  return temp;
}

void setHighTempF(uint8_t address, float temperatureF) {
  setTempRegister(address, T_HIGH_REGISTER, (temperatureF - 32) * 5 / 9);
}

void setLowTempF(uint8_t address, float temperatureF) {
  setTempRegister(address, T_LOW_REGISTER, (temperatureF - 32) * 5 / 9);
}

void setTempRegister(uint8_t address, uint8_t reg, float temperatureC) {
  int16_t temp = temperatureC / 0.0625;
  uint8_t msb = (temp >> 4) & 0xFF;
  uint8_t lsb = (temp << 4) & 0xF0;

  Wire.beginTransmission(address);
  Wire.write(reg);
  Wire.write(msb);
  Wire.write(lsb);
  Wire.endTransmission();
}

void setConversionRate(uint8_t address, uint8_t rate) {
  rate = (rate & 0x03) << 6;
  uint16_t config = readConfigRegister(address);
  config = (config & 0x3FFF) | rate;

  writeConfigRegister(address, config);
}

void setExtendedMode(uint8_t address, bool mode) {
  uint16_t config = readConfigRegister(address);
  config = mode ? (config | 0x0010) : (config & 0xFFEF);

  writeConfigRegister(address, config);
}

void setAlertPolarity(uint8_t address, bool polarity) {
  uint16_t config = readConfigRegister(address);
  config = polarity ? (config | 0x0400) : (config & 0xFBFF);

  writeConfigRegister(address, config);
}

void setAlertMode(uint8_t address, bool mode) {
  uint16_t config = readConfigRegister(address);
  config = mode ? (config | 0x0200) : (config & 0xFDFF);

  writeConfigRegister(address, config);
}

void setFaultQueue(uint8_t address, uint8_t faults) {
  faults = (faults & 0x03) << 3;
  uint16_t config = readConfigRegister(address);
  config = (config & 0xFFF7) | faults;

  writeConfigRegister(address, config);
}

uint16_t readConfigRegister(uint8_t address) {
  Wire.beginTransmission(address);
  Wire.write(CONFIG_REGISTER);
  Wire.endTransmission();
  Wire.requestFrom(address, (uint8_t)2);  // Request 2 bytes from the config register

  uint8_t msb = Wire.read();
  uint8_t lsb = Wire.read();
  return (msb << 8) | lsb;
}

void writeConfigRegister(uint8_t address, uint16_t config) {
  Wire.beginTransmission(address);
  Wire.write(CONFIG_REGISTER);
  Wire.write(config >> 8);
  Wire.write(config & 0xFF);
  Wire.endTransmission();
}

byte receivedByte;
//Slave receive event
void receiveEvent(int numBytes) {
  //Serial.print("Slave Received: ");

  if (numBytes == 0) return;

  receivedByte = 0;
  while (Wire1.available()) {
    receivedByte = Wire1.read();  // Read the received byte
    //Serial.println(receivedByte, HEX); // Print received byte in HEX format
  }
}


//Slave request event
uint8_t command_high_nibble = 0;
uint16_t command_low_nibble = 0;
uint8_t moduleIndex = 0;
int16_t MinValue = 0xFD80;
int16_t AvgValue = 0x05D0;
int16_t MaxValue = 0x07D0;
void requestEvent() {
  command_high_nibble = receivedByte >> 4;
  command_low_nibble = receivedByte & 0b00001111;
  // Serial.print("command_high_nibble: ");
  // Serial.print(command_high_nibble);
  // Serial.print("        ");
  // Serial.print("command_low_nibble: ");
  // Serial.println(command_low_nibble);
  if ((command_high_nibble <= 7) && (command_low_nibble <= 3)) {
    Serial.print("muxIndex: ");
    Serial.print(command_high_nibble);
    Serial.print("        ");
    Serial.print("sensorIndex: ");
    Serial.println(command_low_nibble);
    Wire1.write(sensorValues[command_high_nibble][command_low_nibble] >> 8);
    Wire1.write(sensorValues[command_high_nibble][command_low_nibble]);
  } else if ((command_high_nibble >= 8) && (command_low_nibble <= 2)) {
    // Serial.print("command_high_nibble: ");
    // Serial.print(command_high_nibble);
    moduleIndex = command_high_nibble - 0x8;
    // Serial.print("moduleIndex: ");
    // Serial.print(moduleIndex);
    // Serial.print("        ");
    // Serial.print("Command type: ");
    // Serial.println(command_low_nibble);
    switch (command_low_nibble) {
      case 0:
        Serial.println("Default 0");
        MinValue = calculateModuleMin(moduleIndex); 
        //MinValue = 0x07D0;
        Wire1.write(MinValue >> 8);
        Wire1.write(MinValue);
        break;
      case 1:
        Serial.println("Default 1");
        AvgValue = calculateModuleAverage(moduleIndex); 
        //AvgValue = 0x05D0;
        Wire1.write(AvgValue >> 8);
        Wire1.write(AvgValue);
        // AvgValue += 60;
        // if(AvgValue >= (125*16)){
        //   AvgValue = -40*16;
        // }
        break;
      case 2:
        Serial.println("Default 2");
        MaxValue = calculateModuleMax(moduleIndex); 
        //MaxValue = 0xFD80;
        Wire1.write(MaxValue >> 8);
        Wire1.write(MaxValue);
        break;
      default:
        Serial.print("Default");
        break;
    }
  }
}

int16_t calculateModuleMax(uint8_t module) {
  int16_t max = 0x8000;
  for (int i = 0; i < NUMBER_OF_MUX_PORTS; i++) {
    //mux.setPort(i);
    for (int j = 0; j < NUMBER_OF_TMP_ADDRESSES; j++) {
      if (connectedSensors[i][j] == module && sensorValues[i][j] > max) {
        max = sensorValues[i][j];
      }
      
    }
  }
  Serial.print("max:");
  Serial.println(max*0.0625);
  return max;
}

int16_t calculateModuleMin(uint8_t module) {
  int16_t min = 0x7FFF;  //Larger than sensor will ever report
  for (int i = 0; i < NUMBER_OF_MUX_PORTS; i++) {
    //mux.setPort(i);
    for (int j = 0; j < NUMBER_OF_TMP_ADDRESSES; j++) {
      if (connectedSensors[i][j] == module && sensorValues[i][j] < min) {
        min = sensorValues[i][j];
      }
      
    }
  }
  Serial.print("min:");
  Serial.println(min*0.0625);
  return min;
}

int16_t calculateModuleAverage(uint8_t module) {
  int16_t average = 0;
  int16_t averageCounter = 0;
  for (int i = 0; i < NUMBER_OF_MUX_PORTS; i++) {
    //mux.setPort(i);
    for (int j = 0; j < NUMBER_OF_TMP_ADDRESSES; j++) {
      if (connectedSensors[i][j] == module) {
        average += sensorValues[i][j];
        averageCounter++;
      }

      
    }
  }
  average /= averageCounter;   
  average = (int16_t) average;
  Serial.print("average:");
  Serial.println(average*0.0625);      
  return average;
}

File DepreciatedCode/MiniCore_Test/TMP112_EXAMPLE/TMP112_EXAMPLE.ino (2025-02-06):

#include <Wire.h>
#include <Wire1.h>

#define TMP102_ADDRESS 0x48
#define TEMPERATURE_REGISTER 0x00
#define CONFIG_REGISTER 0x01
#define T_LOW_REGISTER 0x02
#define T_HIGH_REGISTER 0x03
#define ALERT_PIN A3
#define SLAVE_ADDRESS 0x20

void setup() {
  Serial.begin(9600);
  Wire.begin();
  pinMode(ALERT_PIN, INPUT);

  if (!initializeTMP102()) {
    Serial.println("Cannot connect to TMP102. Check wiring and address.");
    while (1);
  }
  // Initialize the secondary I2C bus as a Slave
  Wire1.begin(SLAVE_ADDRESS);
  Wire1.onReceive(receiveEvent); // Callback for data received
  Wire1.onRequest(requestEvent); // Callback for data requested
  Serial.println("Slave I2C Initialized");
  configureSensor();
}

void loop() {
  float temperatureC = readTempC();
  float temperatureF = temperatureC * 9.0 / 5.0 + 32.0;
  
  //Serial.print("Temperature: ");
  //Serial.print(temperatureC);
  //Serial.print("°C / ");
  Serial.println(temperatureF);
  //Serial.print("°F");

  int alertPinState = digitalRead(ALERT_PIN);
  //Serial.print("\tAlert Pin State: ");
  //Serial.println(alertPinState);

  delay(100);
}

bool initializeTMP102() {
  Wire.beginTransmission(TMP102_ADDRESS);
  return Wire.endTransmission() == 0;
}

void configureSensor() {
  setConversionRate(2);        // Set conversion rate to 4 Hz
  setExtendedMode(true);      // Standard mode (-55°C to 128°C)
  setAlertPolarity(true);      // Active HIGH alert
  setAlertMode(false);         // Comparator mode
  setFaultQueue(0);            // Trigger alert on first fault
  setHighTempF(85.0);          // Set T_HIGH threshold to 85°F
  setLowTempF(84.0);           // Set T_LOW threshold to 84°F
}

float readTempC() {
  Wire.beginTransmission(TMP102_ADDRESS);
  Wire.write(TEMPERATURE_REGISTER);
  Wire.endTransmission();
  Wire.requestFrom(TMP102_ADDRESS, 2);

  uint8_t msb = Wire.read();
  uint8_t lsb = Wire.read();
  
  int temp = (msb << 5) | (lsb >> 3); // 13-bit mode (left-justified)
  if (temp & 0x1000) temp |= 0xE000; // Sign extend negative numbers
  
  return temp * 0.0625;
}

void setHighTempF(float temperatureF) {
  setTempRegister(T_HIGH_REGISTER, (temperatureF - 32) * 5 / 9);
}

void setLowTempF(float temperatureF) {
  setTempRegister(T_LOW_REGISTER, (temperatureF - 32) * 5 / 9);
}

void setTempRegister(uint8_t reg, float temperatureC) {
  int16_t temp = temperatureC / 0.0625;
  uint8_t msb = (temp >> 4) & 0xFF;
  uint8_t lsb = (temp << 4) & 0xF0;
  
  Wire.beginTransmission(TMP102_ADDRESS);
  Wire.write(reg);
  Wire.write(msb);
  Wire.write(lsb);
  Wire.endTransmission();
}

void setConversionRate(uint8_t rate) {
  rate = (rate & 0x03) << 6;
  uint16_t config = readConfigRegister();
  config = (config & 0x3FFF) | rate;

  writeConfigRegister(config);
}

void setExtendedMode(bool mode) {
  uint16_t config = readConfigRegister();
  config = mode ? (config | 0x0010) : (config & 0xFFEF);

  writeConfigRegister(config);
}

void setAlertPolarity(bool polarity) {
  uint16_t config = readConfigRegister();
  config = polarity ? (config | 0x0400) : (config & 0xFBFF);

  writeConfigRegister(config);
}

void setAlertMode(bool mode) {
  uint16_t config = readConfigRegister();
  config = mode ? (config | 0x0200) : (config & 0xFDFF);

  writeConfigRegister(config);
}

void setFaultQueue(uint8_t faults) {
  faults = (faults & 0x03) << 3;
  uint16_t config = readConfigRegister();
  config = (config & 0xFFF7) | faults;

  writeConfigRegister(config);
}

uint16_t readConfigRegister() {
  Wire.beginTransmission(TMP102_ADDRESS);
  Wire.write(CONFIG_REGISTER);
  Wire.endTransmission();
  Wire.requestFrom(TMP102_ADDRESS, 2);

  uint8_t msb = Wire.read();
  uint8_t lsb = Wire.read();
  return (msb << 8) | lsb;
}

void writeConfigRegister(uint16_t config) {
  Wire.beginTransmission(TMP102_ADDRESS);
  Wire.write(CONFIG_REGISTER);
  Wire.write(config >> 8);
  Wire.write(config & 0xFF);
  Wire.endTransmission();
}
// Slave receive event
void receiveEvent(int numBytes) {
  Serial.print("Slave Received: ");
  while (Wire1.available()) {
    char c = Wire1.read();
    Serial.print(c); // Print received byte
  }
  Serial.println();
}

// Slave request event
void requestEvent() {
  Serial.println("Here");
  Wire1.write(1); // Send a response to the master
}

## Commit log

2024-12-04 Working I2c MUX
2024-12-12 "verified" up to 32 sensor reading
2025-01-15 Slave + master + i2c one bus
2025-01-22 Updated with thermal profile nad example data collection and plotter
    [Team_9_01212025_173548.csv, Team_9_01212025_173807.csv]
2025-02-18 Digital Filtering and Module Values
    [Team_9_01212025_173807.csv]
2025-02-19 Fixed min, max, average, calculations
    [NormalOperation.ino]
2025-02-19 Fixed hard coded average
    [NormalOperation.ino]
2025-03-17 PWR/GND Change
